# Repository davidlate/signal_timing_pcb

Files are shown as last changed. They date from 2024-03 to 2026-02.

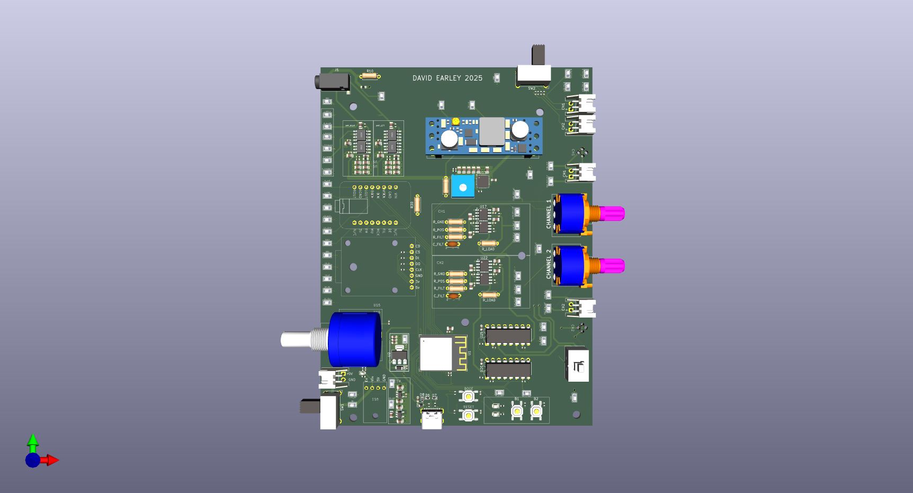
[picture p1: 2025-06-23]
20250622_SignalTimingProject_3DModelView_Rev5.png

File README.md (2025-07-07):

# Signal Timing PCB
This is a project to produce repeated audio pulses which are precisely timed with the outputs of two
current regulated, square wave AC outputs

This repo is divided into header files and functions for the various parts of the project to allow for testing each component individually

-sdcard operations
-I2S op
-DAC ops
-RMT ops
-GPTimer ops

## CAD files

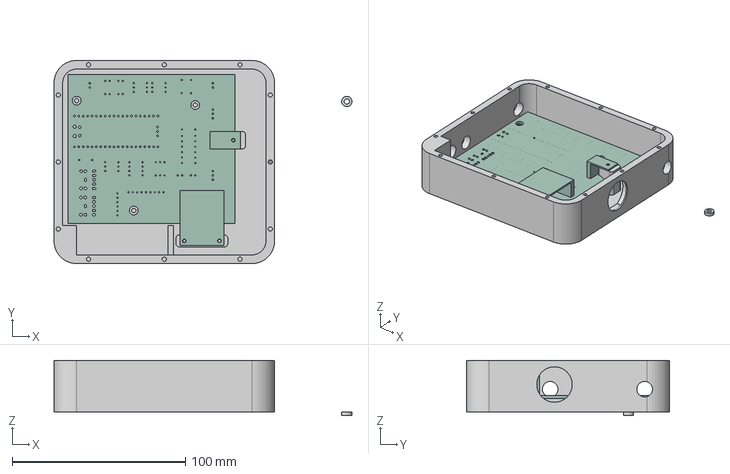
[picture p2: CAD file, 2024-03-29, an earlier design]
app/Archive/rev_1/fixture/bimodal_device_fixture v12.step
172.2 x 117.4 x 32.0 mm

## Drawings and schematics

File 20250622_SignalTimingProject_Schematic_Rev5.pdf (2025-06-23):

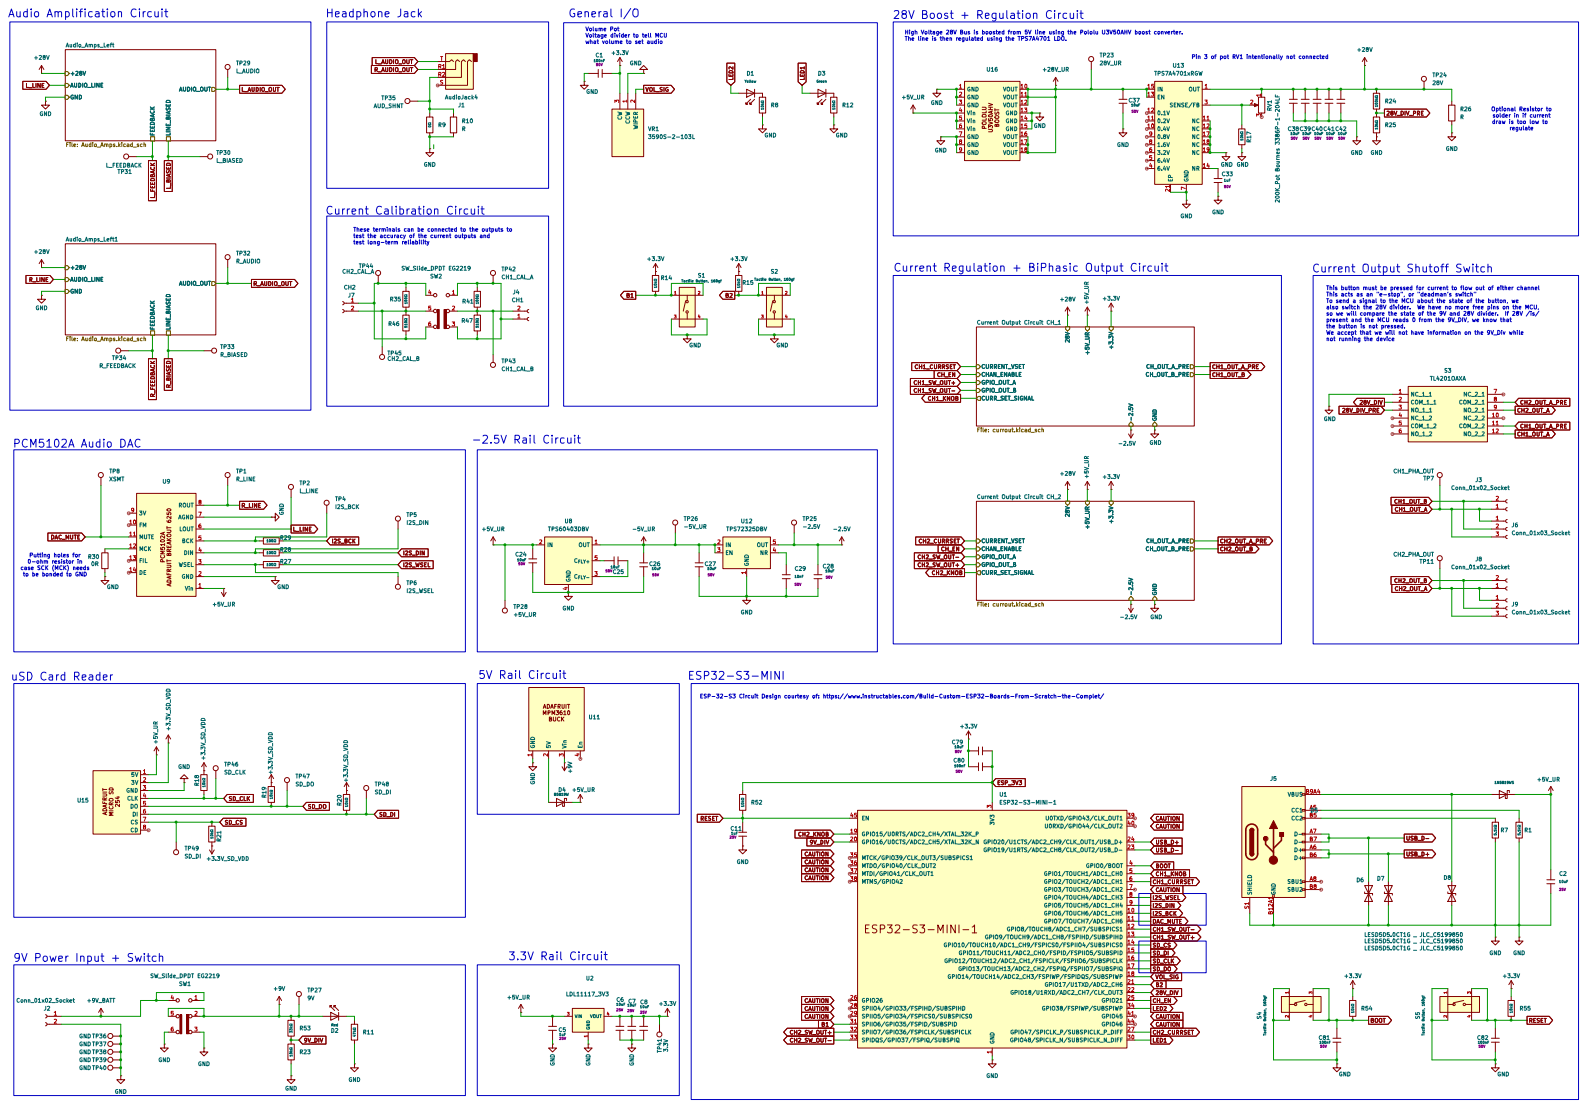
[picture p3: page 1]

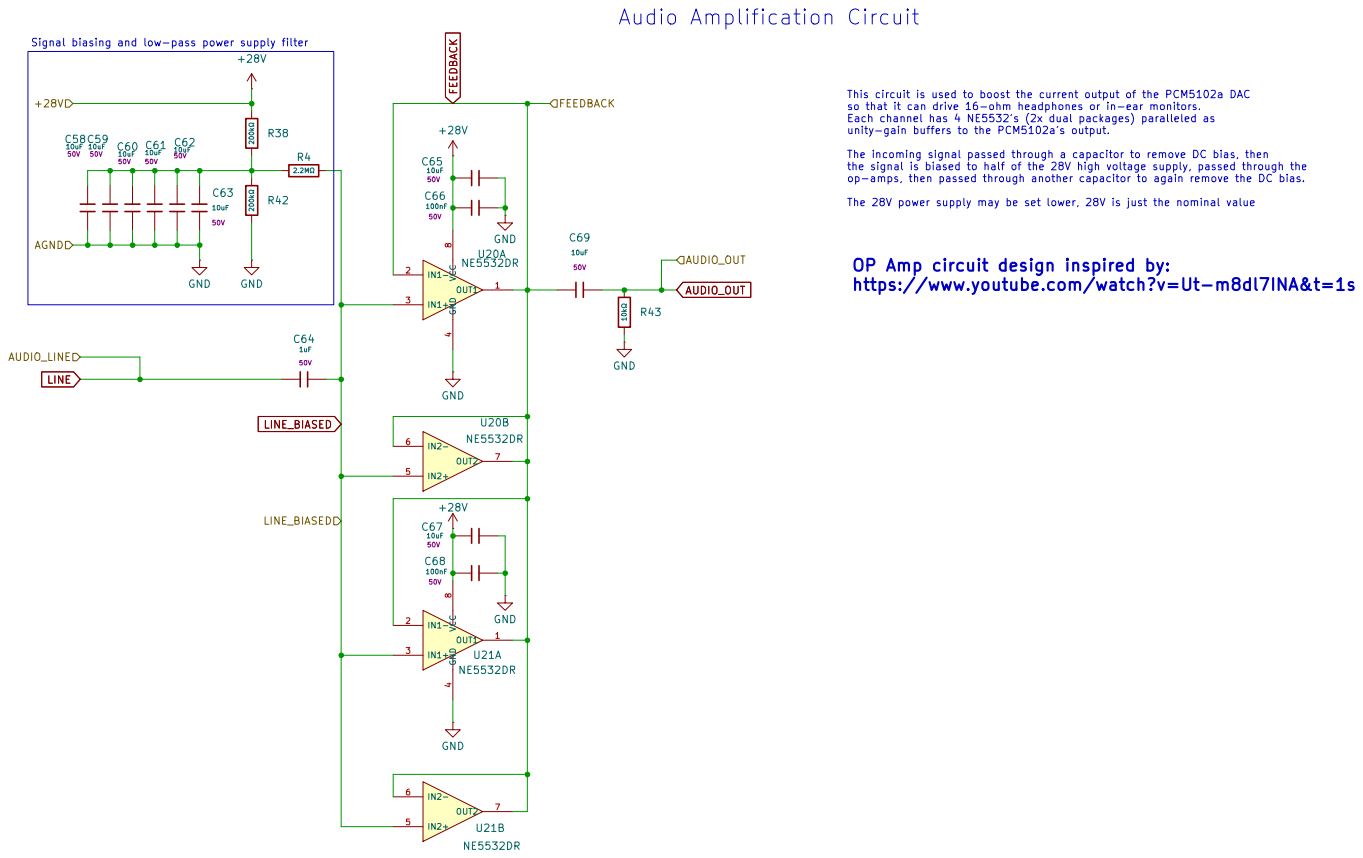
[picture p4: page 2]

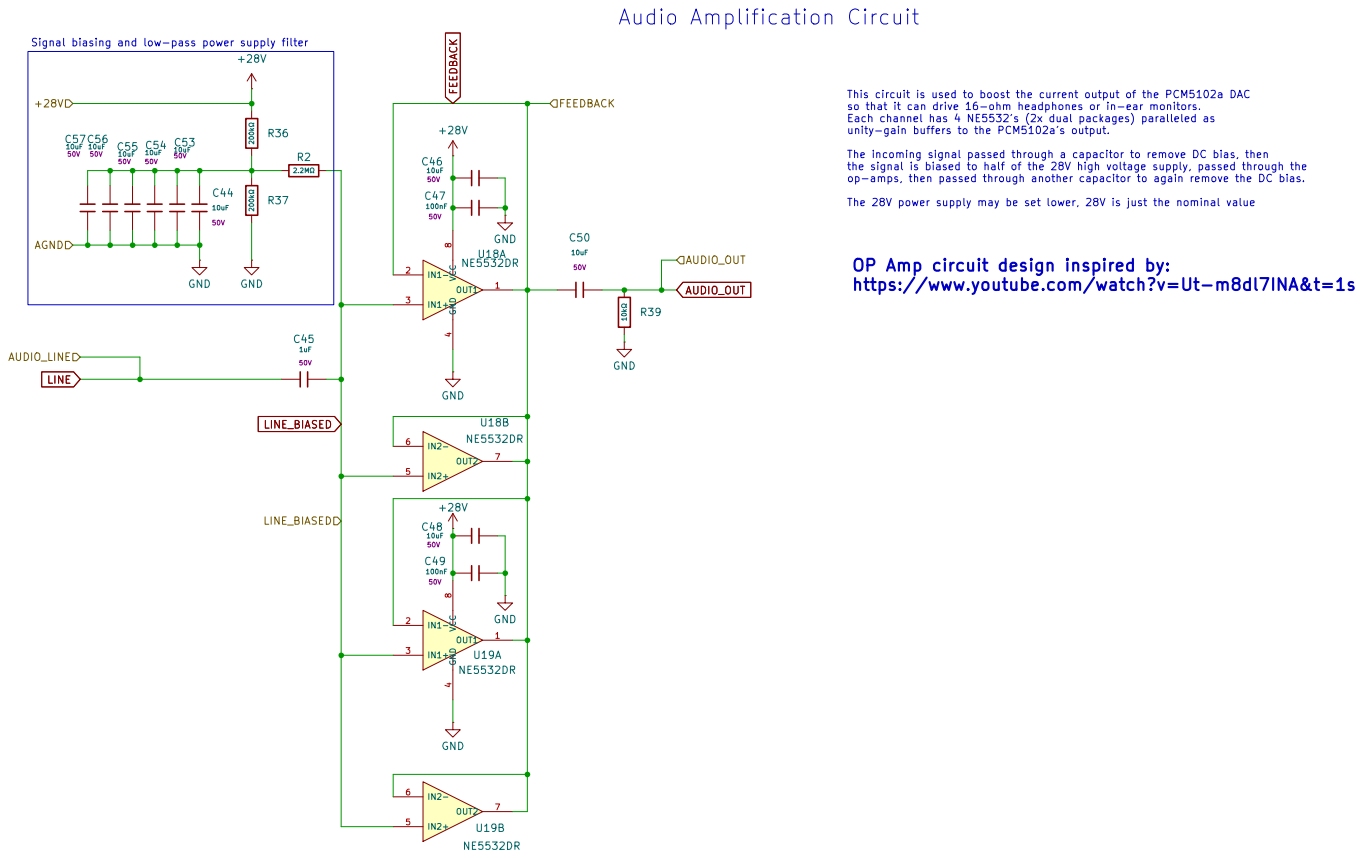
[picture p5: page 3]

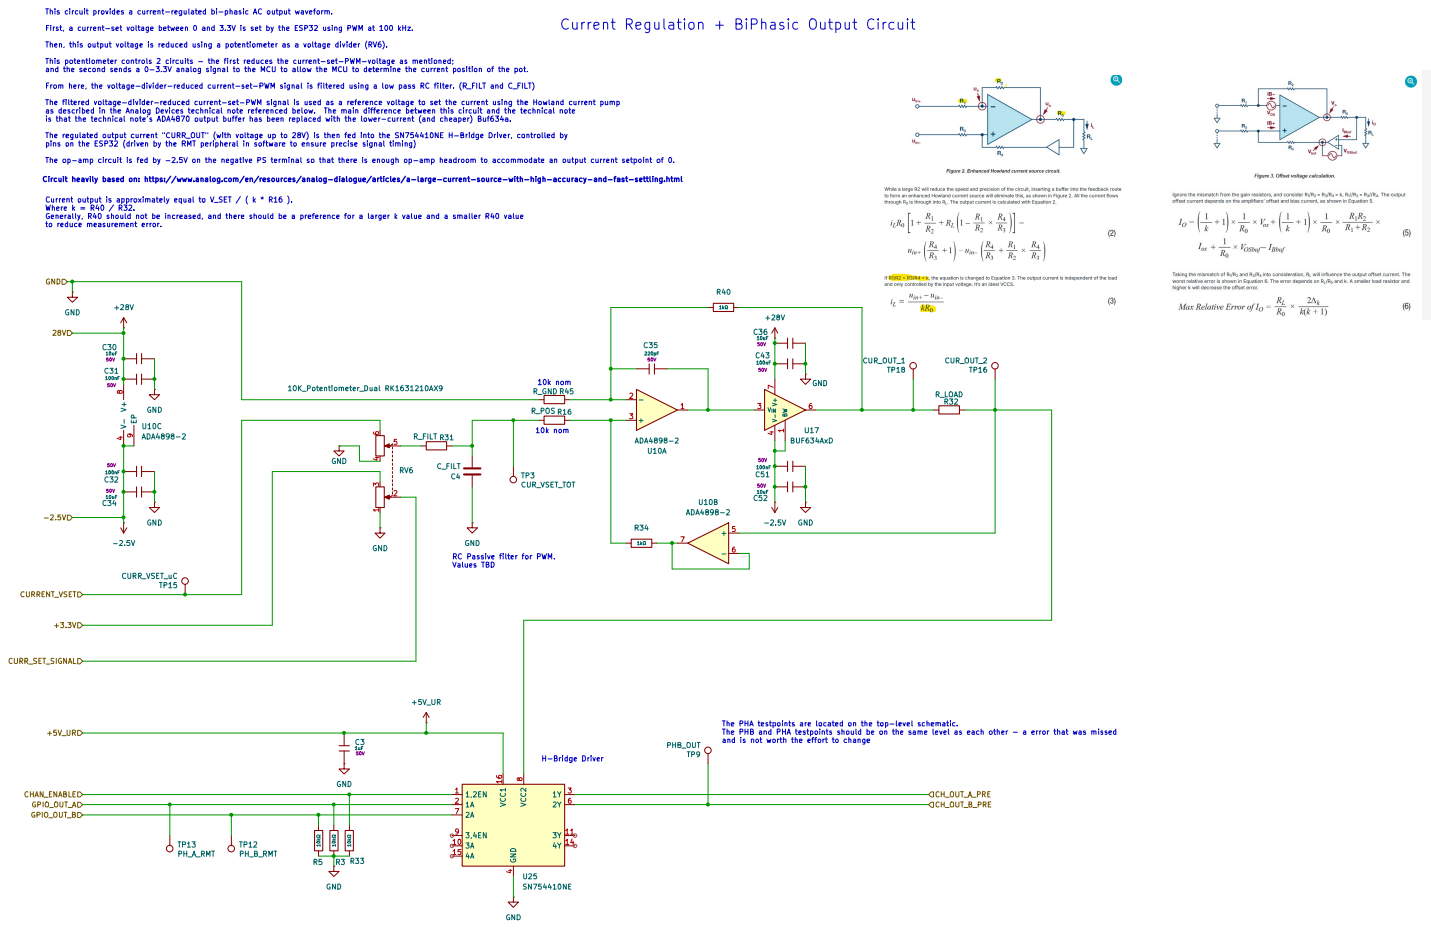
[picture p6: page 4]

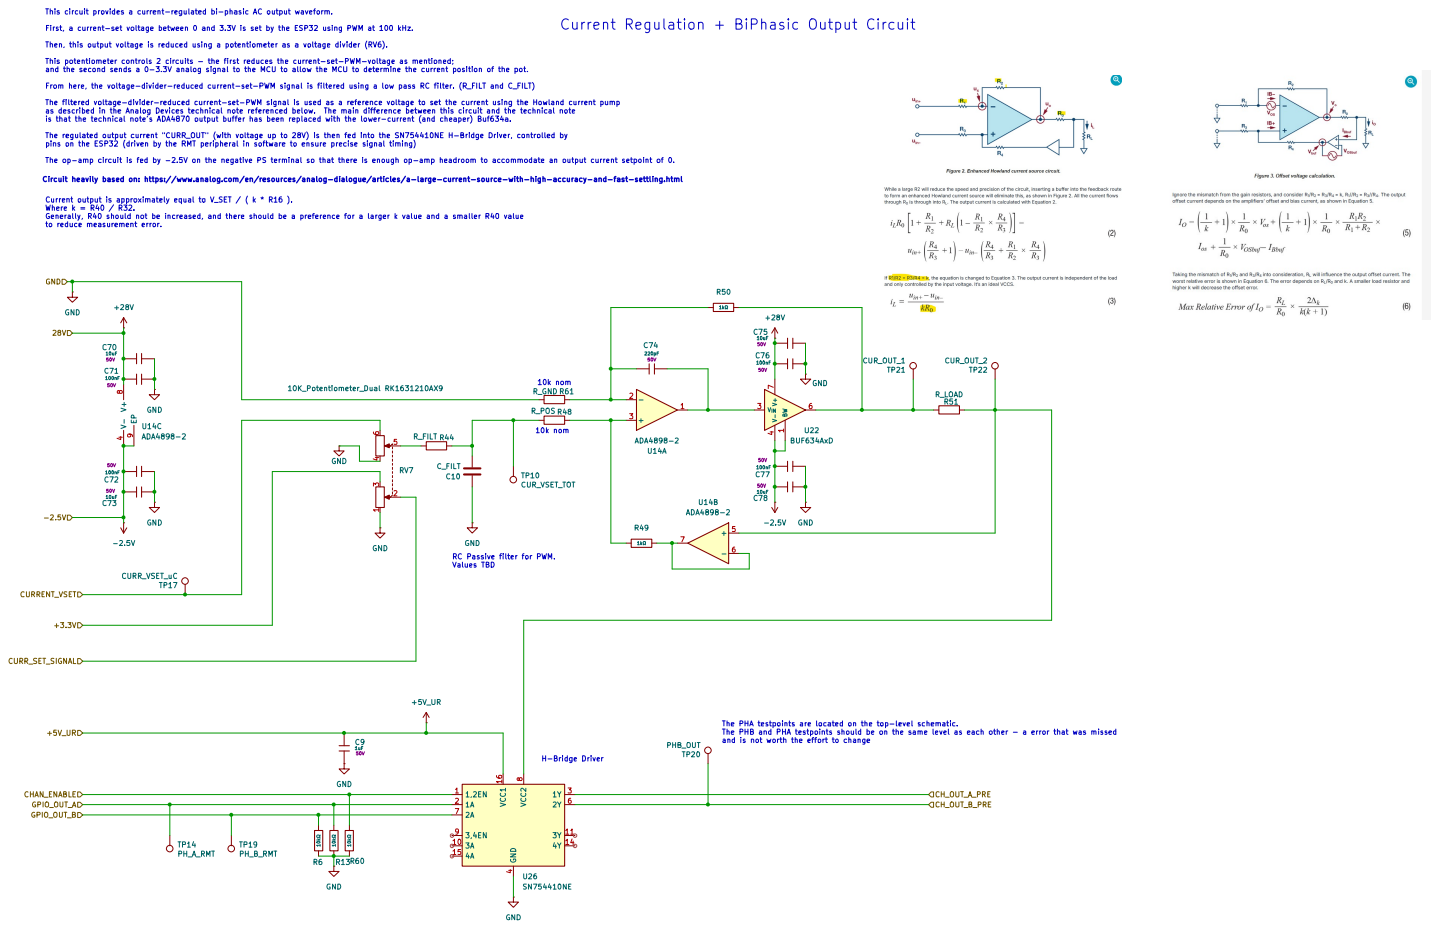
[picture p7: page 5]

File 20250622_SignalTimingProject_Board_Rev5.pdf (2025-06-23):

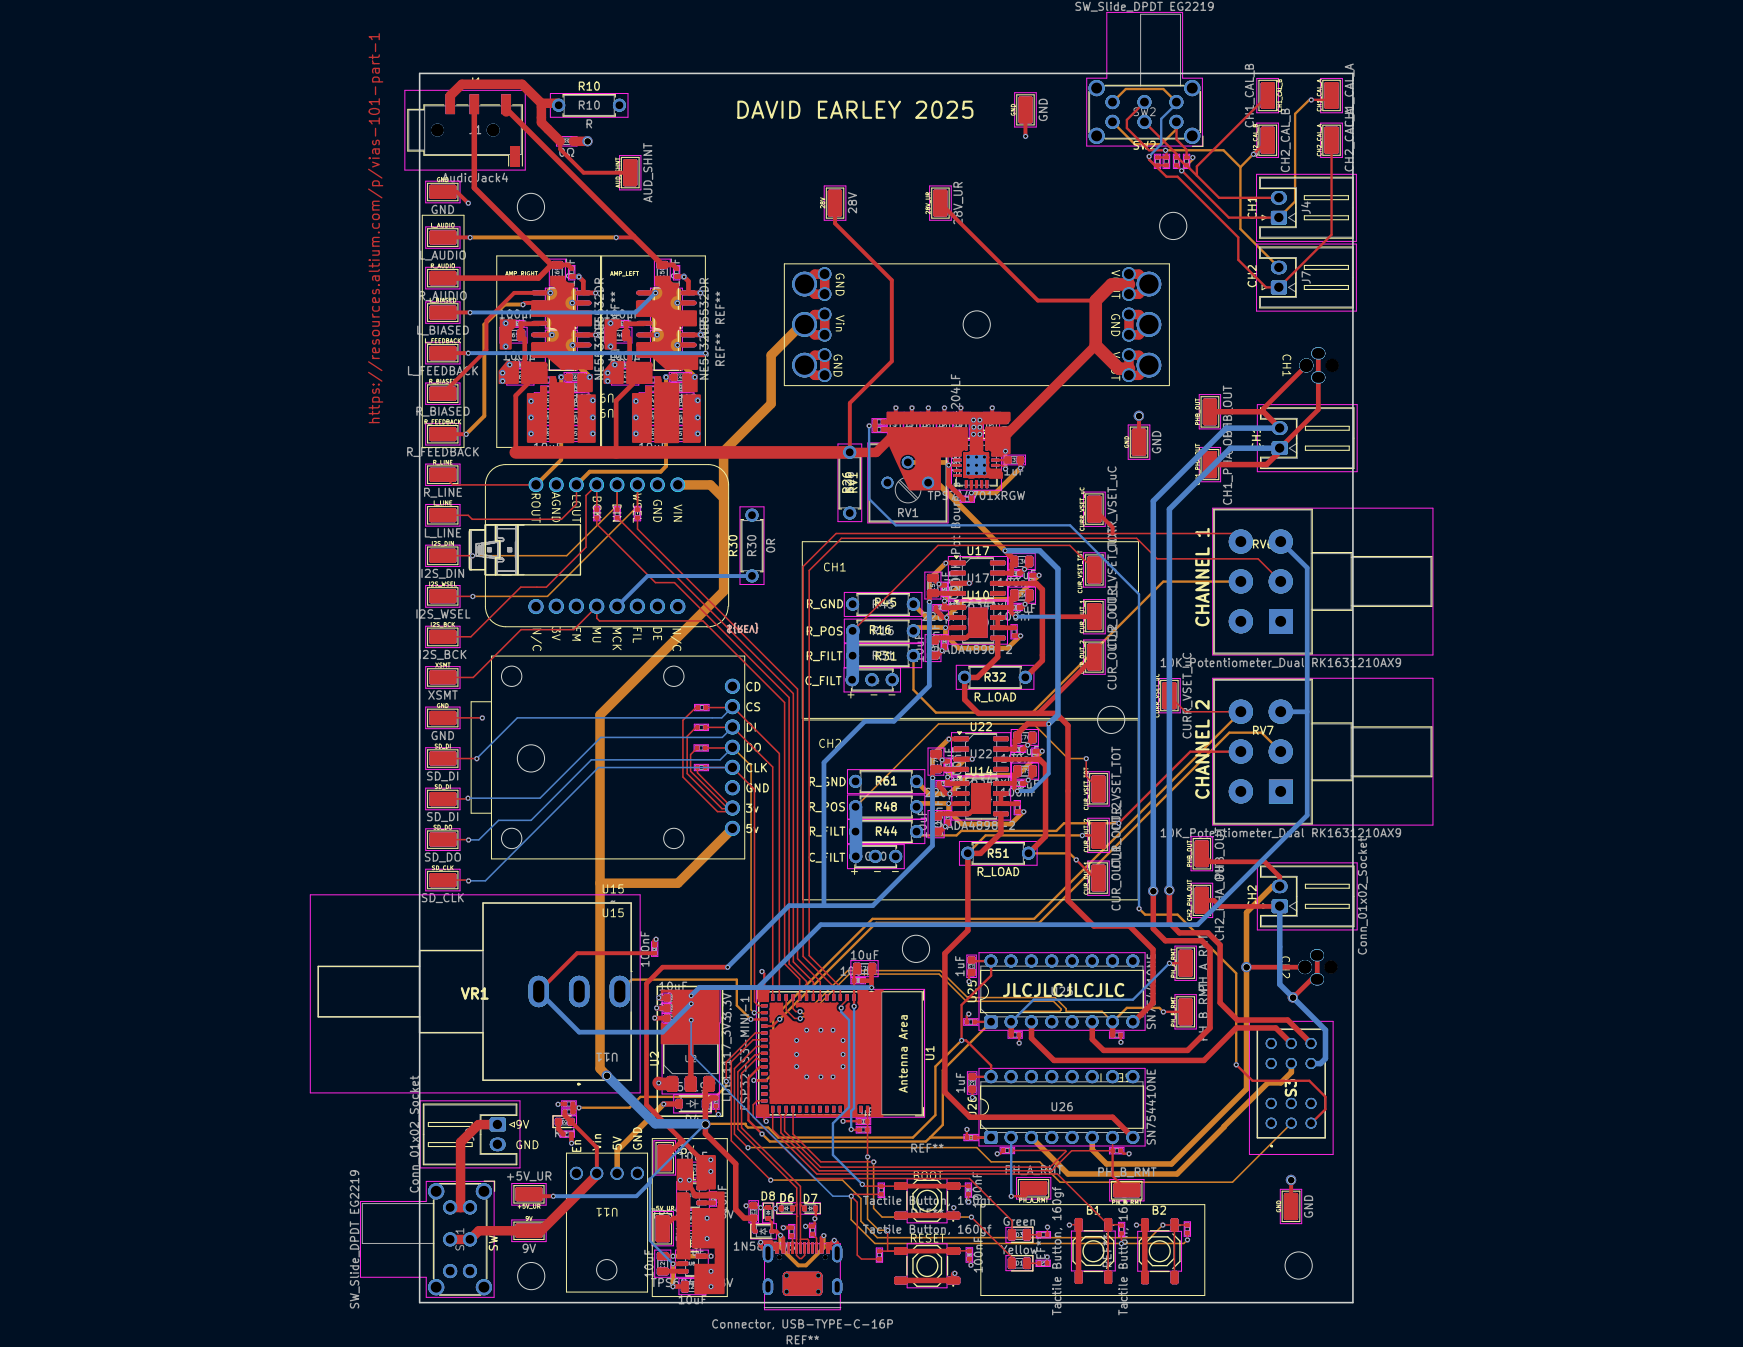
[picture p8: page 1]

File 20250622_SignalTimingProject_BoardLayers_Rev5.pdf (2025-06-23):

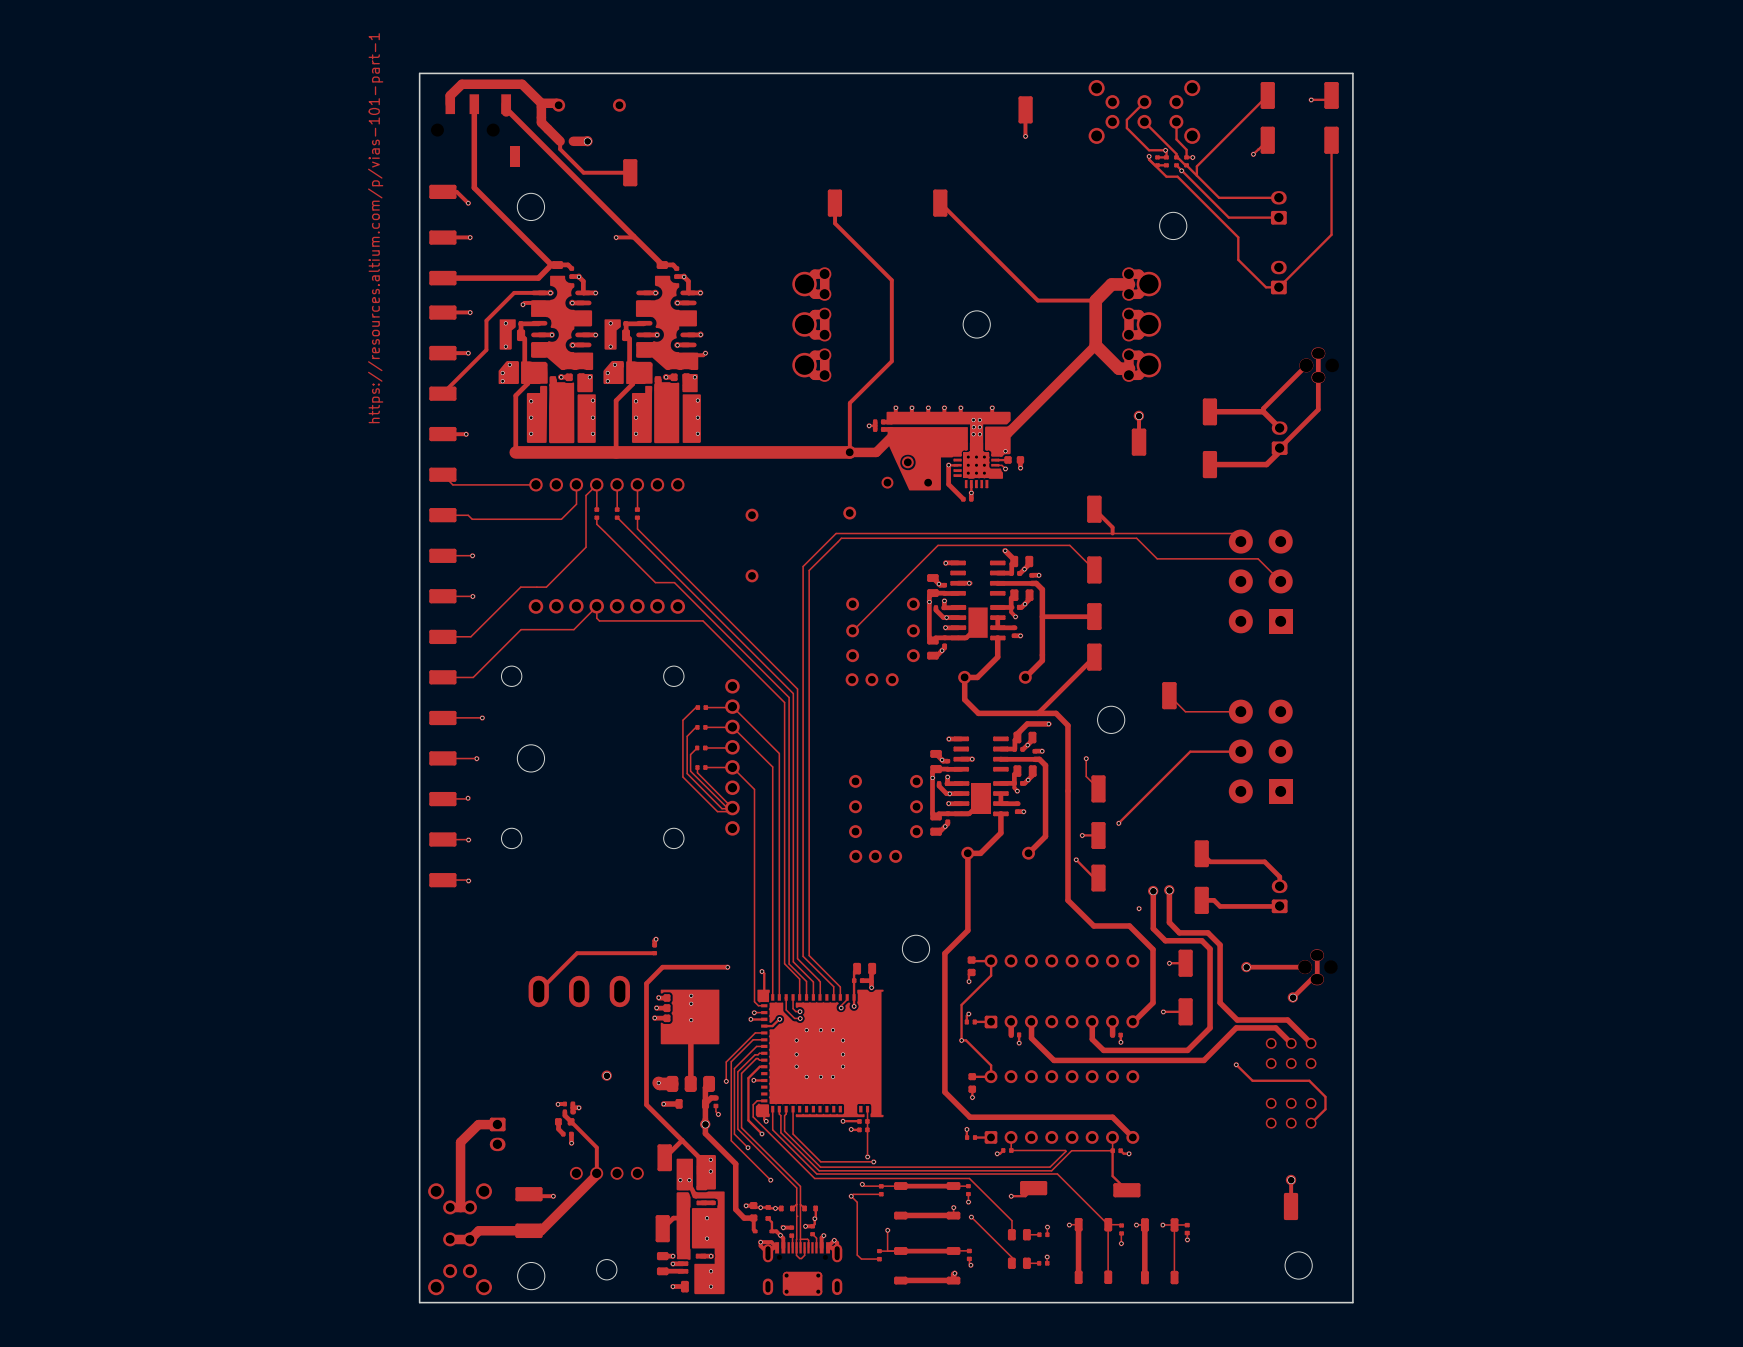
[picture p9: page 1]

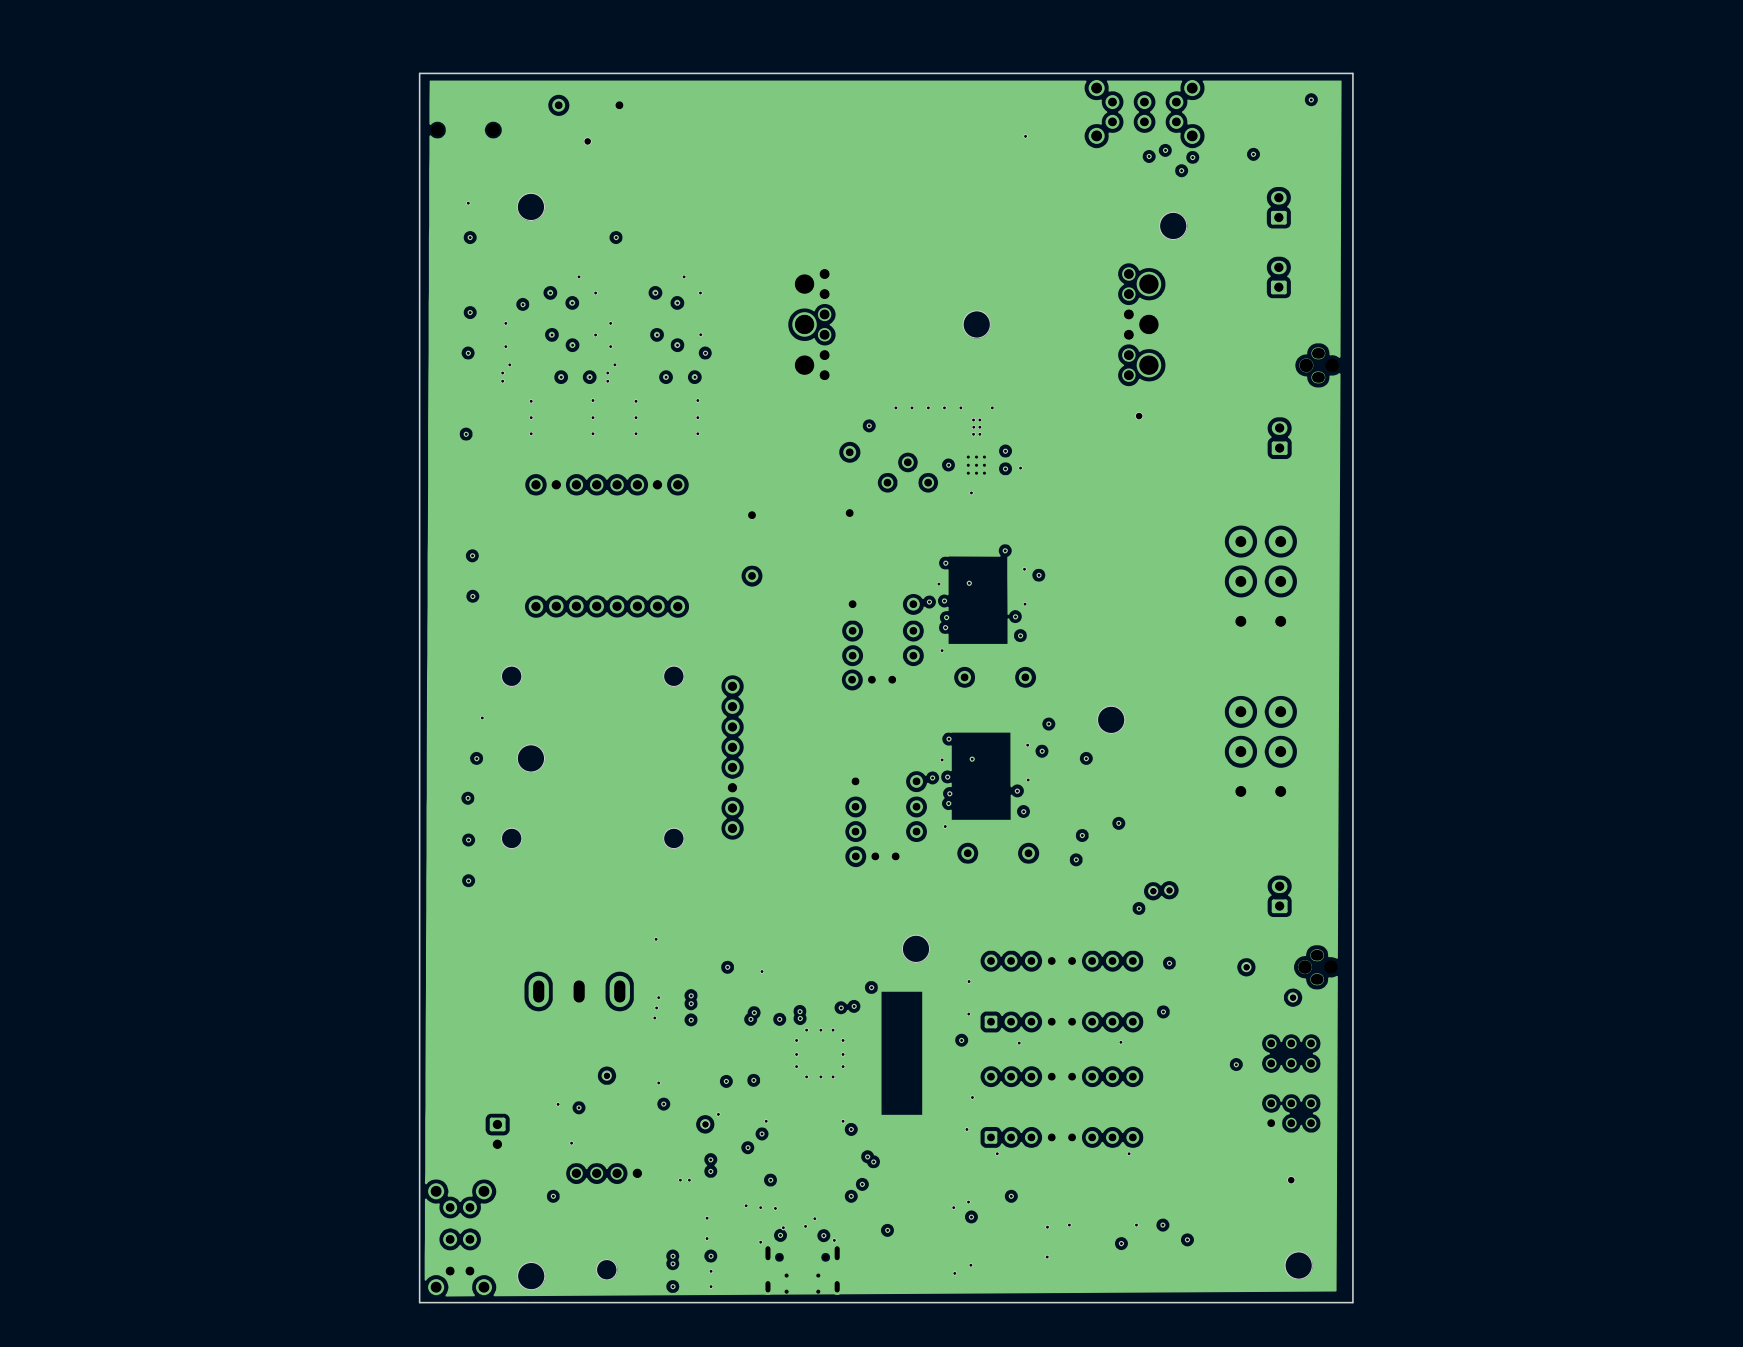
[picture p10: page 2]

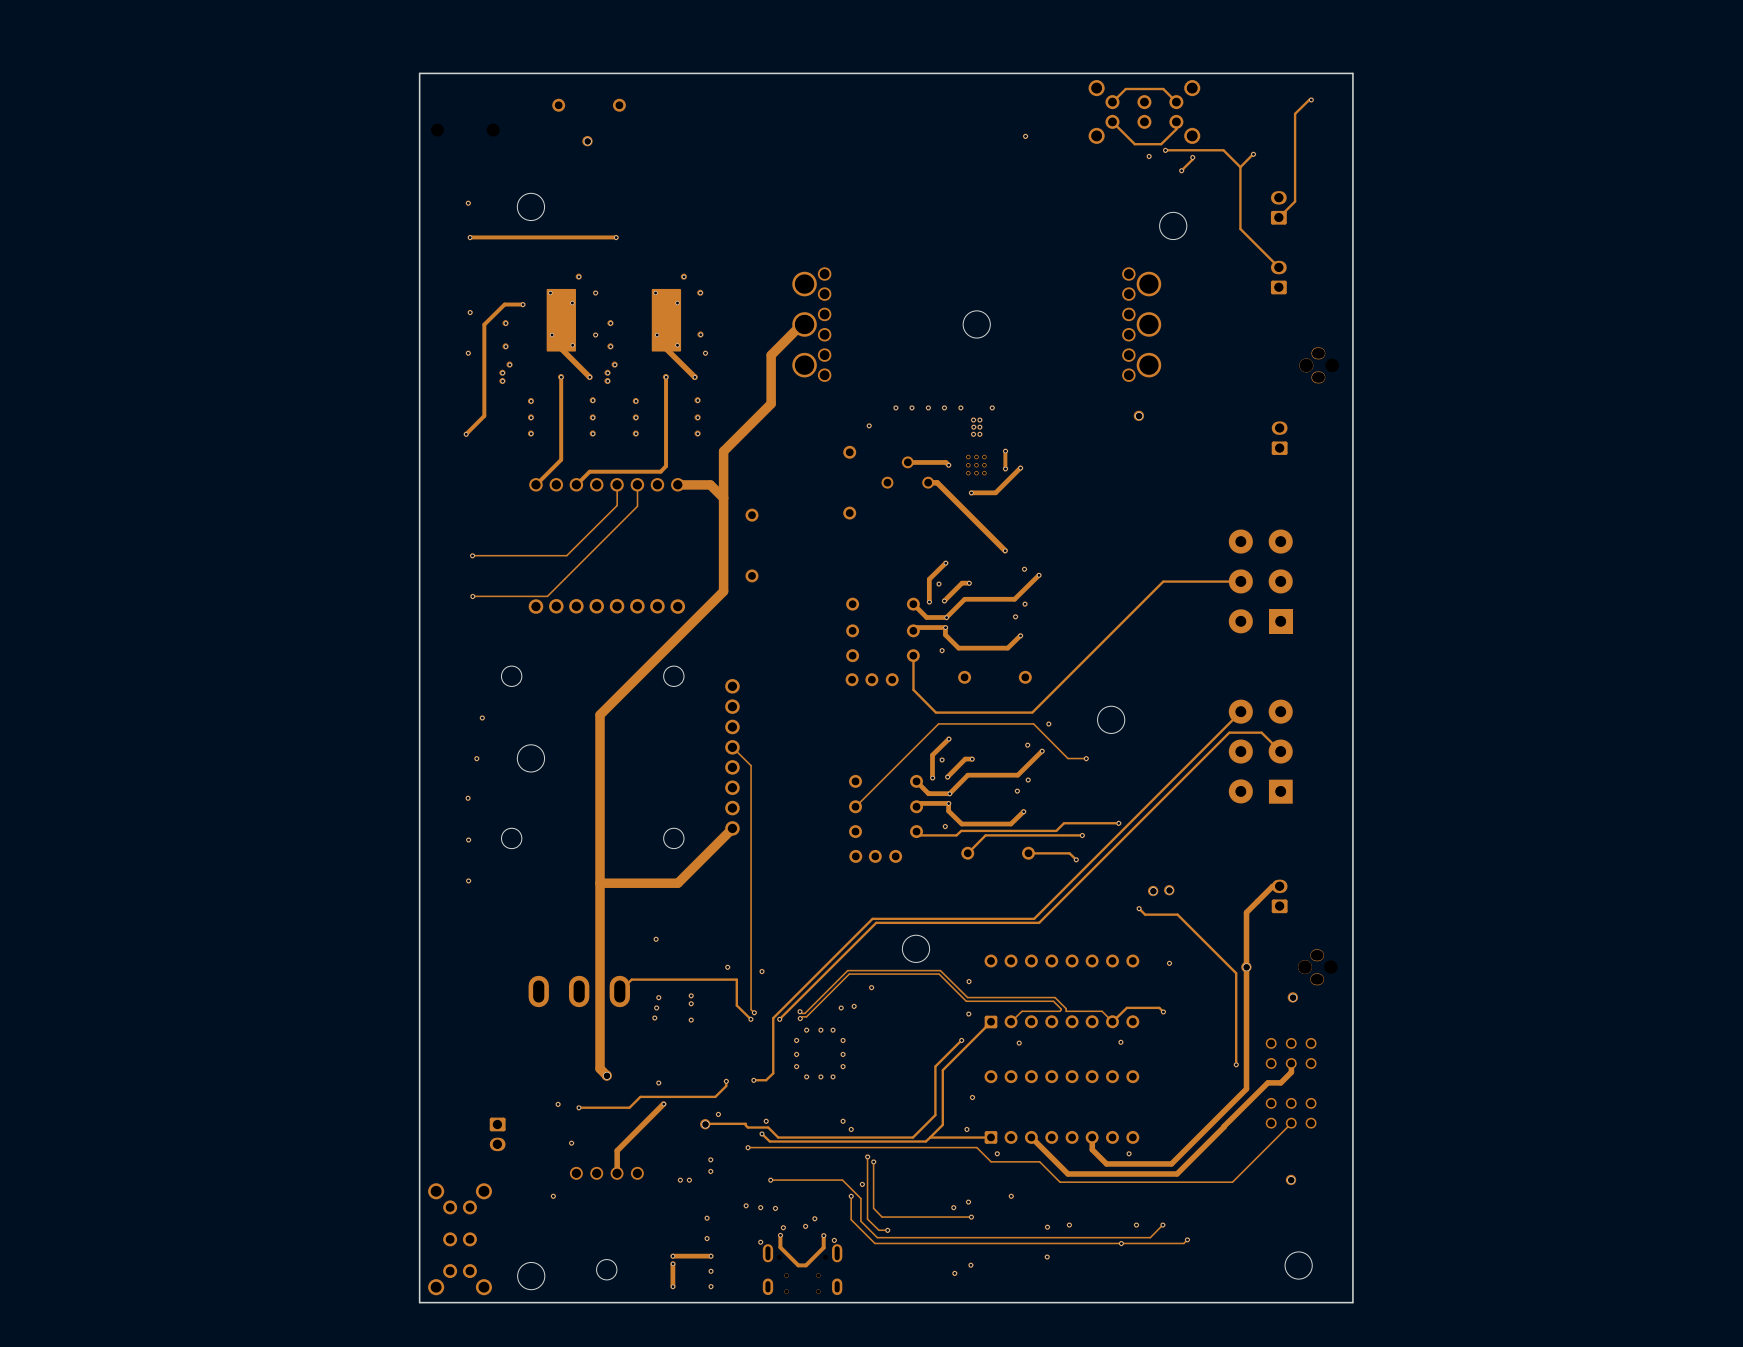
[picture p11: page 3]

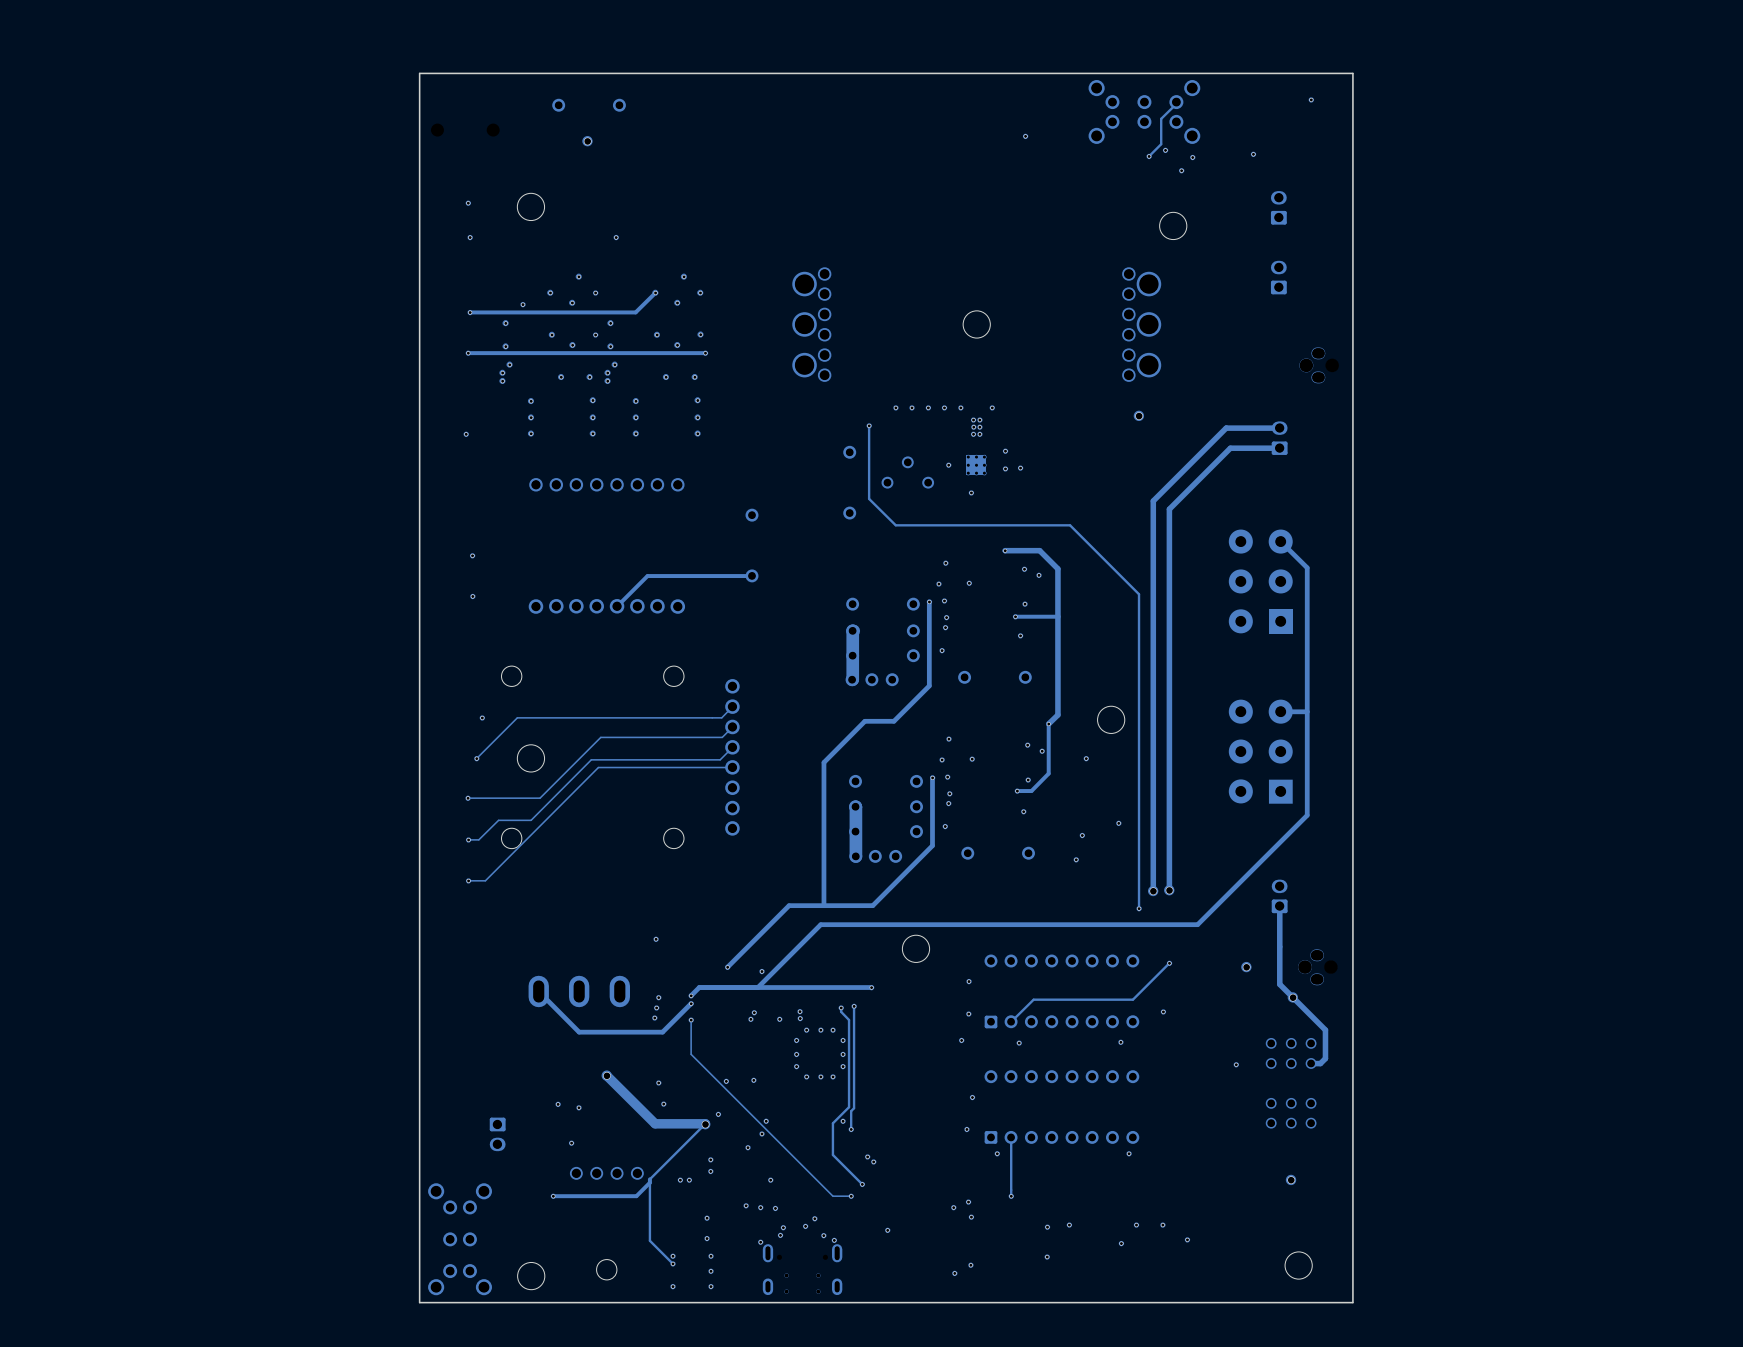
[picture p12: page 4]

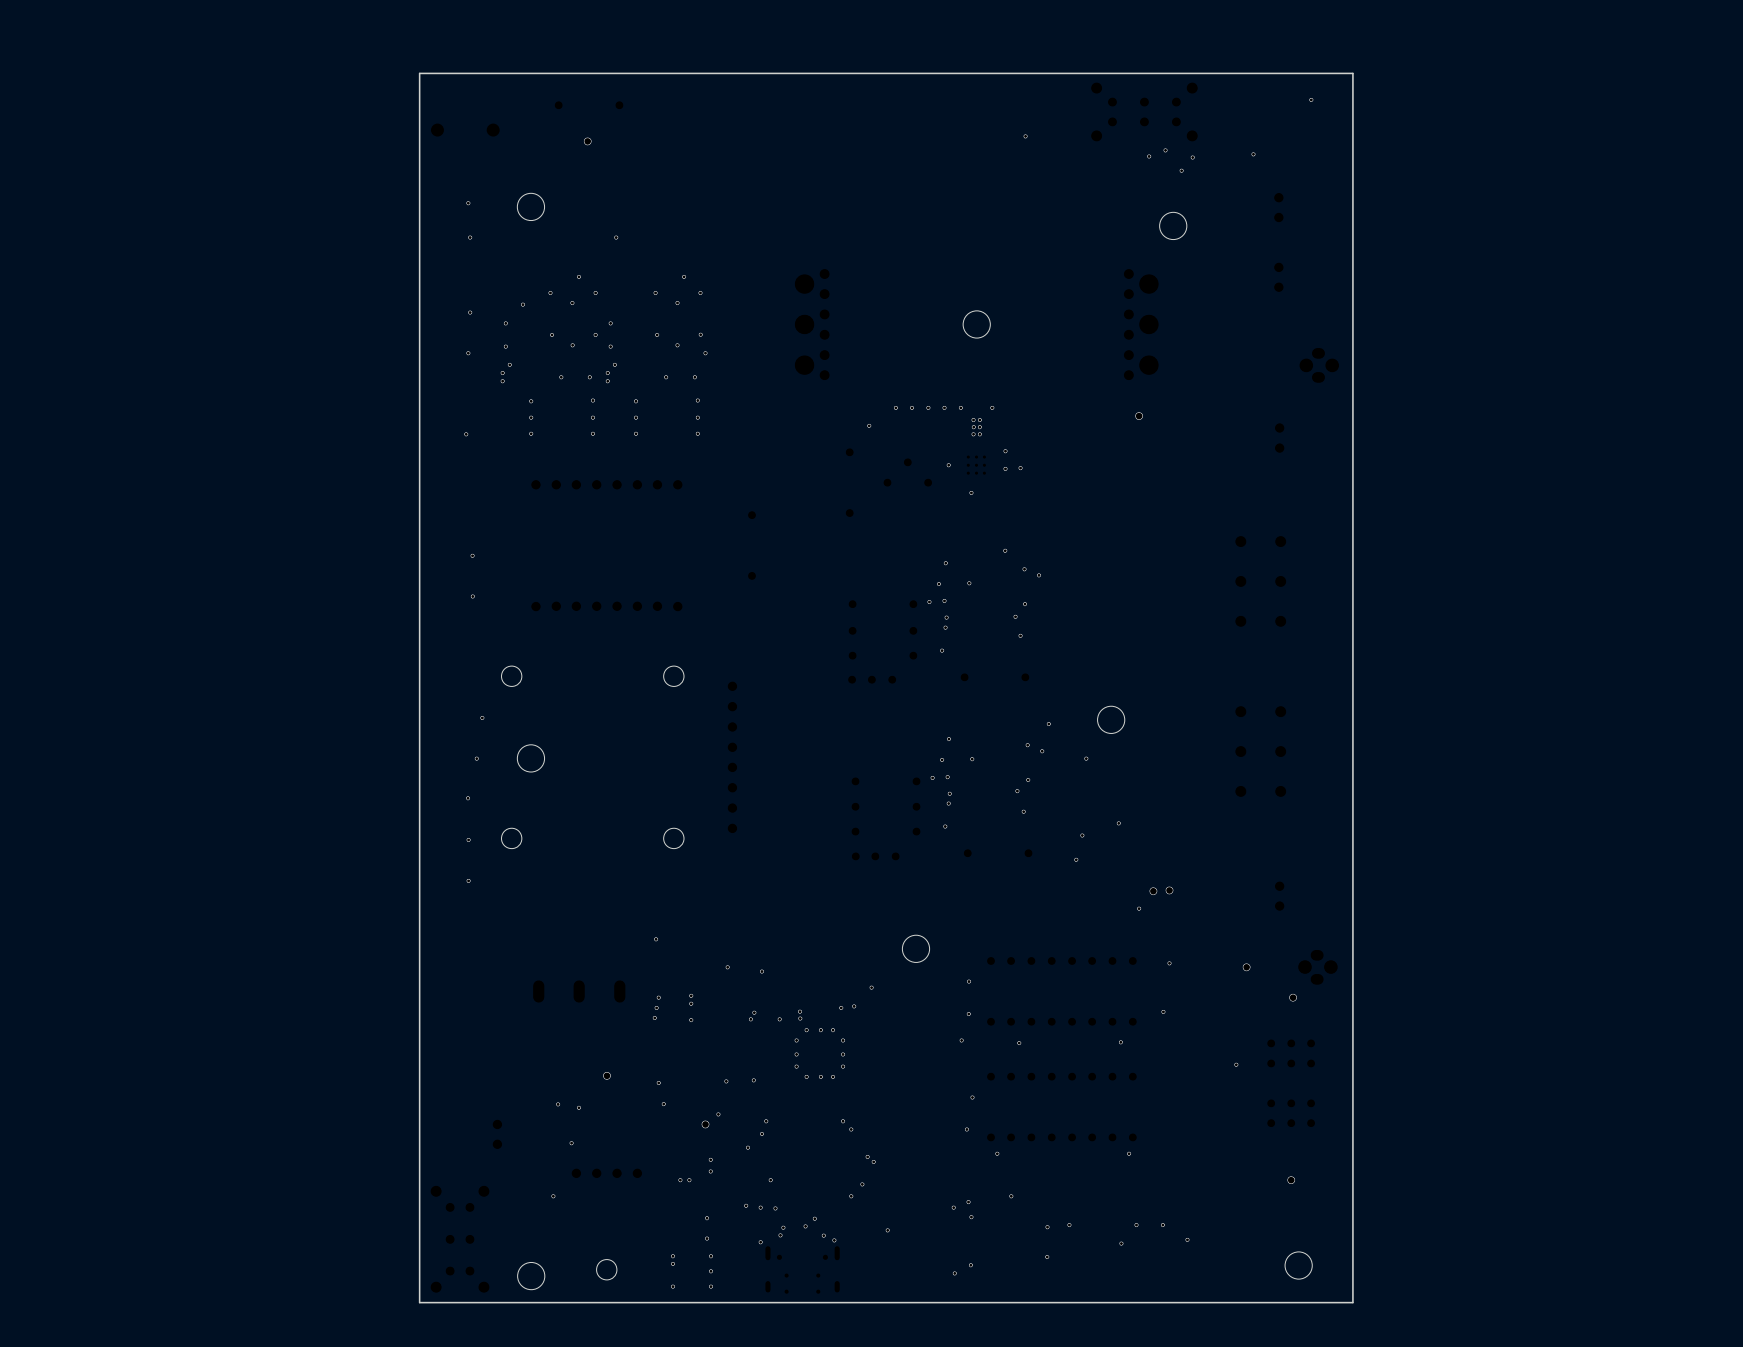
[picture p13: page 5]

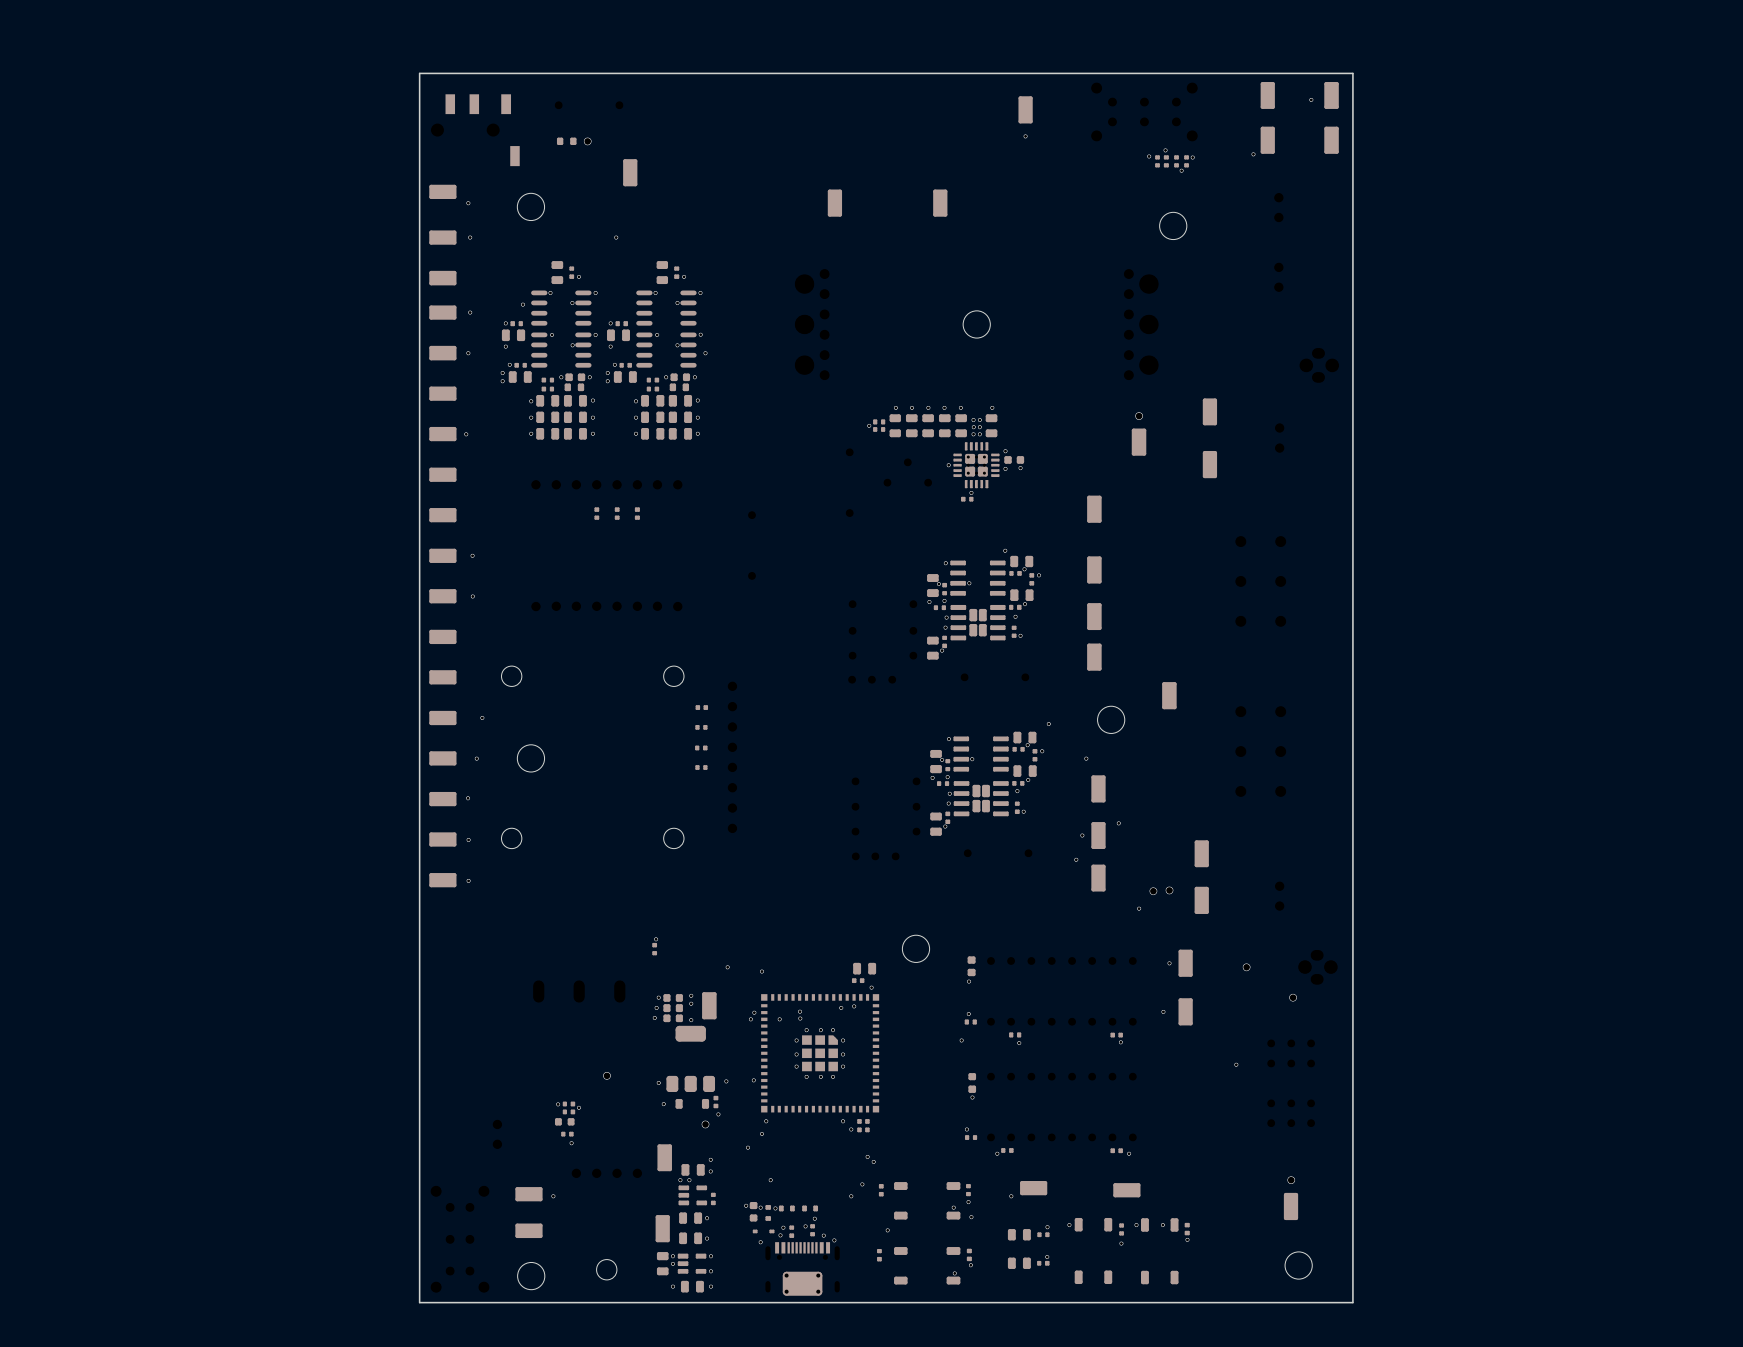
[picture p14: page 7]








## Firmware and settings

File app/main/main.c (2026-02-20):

/* SD card_ptr and FAT filesystem example.
   This example uses SPI peripheral to communicate with SD card_ptr.
*/

//This program is written by David Earley (2025) 
//This program borrows heavily from this article and the Espressif examples throughout:
//https://truelogic.org/wordpress/2015/09/04/parsing-a-wav-file-in-c/

#include <string.h>
#include <sys/unistd.h>
#include <sys/stat.h>
#include "esp_vfs_fat.h"
#include "sdmmc_cmd.h"
#include "sd_test_io.h"
#include <stdio.h>
#include <stdlib.h>
#include <dirent.h> 
#include <inttypes.h>
#include "esp_random.h"
#include "math.h"
#include "esp_timer.h"
#include "driver/gpio.h"
#include "hal/adc_types.h"
#include "esp_adc/adc_oneshot.h"
#include "freertos/queue.h"

#include "driver/ledc.h"
#include "driver/rmt_tx.h"
#include "driver/gptimer.h"
#include <driver/ledc.h>

#include "stp_sd_sdcardops.h"
#include "stp_audio__audio_ops.h"
#include "stp_adc.h"


//SD Card operation defines
#define AUDIO_FILENAME "/SINEA.wav"
// #define AUDIO_FILENAME "/WHITE.wav"

#define PIN_NUM_MISO  GPIO_NUM_13   //DO
#define PIN_NUM_MOSI  GPIO_NUM_11   //DI
#define PIN_NUM_CLK   GPIO_NUM_12   //CLK
#define PIN_NUM_CS    GPIO_NUM_10   //CS

//General IO defines
#define LED1_PIN    48          //GPIO enums only go up to 38
#define LED2_PIN    GPIO_NUM_38
#define XSMT_PIN    GPIO_NUM_7
#define B1_PIN      GPIO_NUM_35
#define B2_PIN      GPIO_NUM_17
//#define CH_EN_PIN   GPIO_NUM_21     //H-bridge enable pin

//ADC Pin and channel defines from schematic and https://www.luisllamas.es/en/esp32-s3-hardware-details-pinout/
//See example https://github.com/espressif/esp-idf/blob/v4.4/examples/peripherals/adc/single_read/single_read/main/single_read.c
#define VOL_PIN         GPIO_NUM_14     //Volume sample DAC pin
#define VOL_ADC_UNIT    ADC_UNIT_2
#define VOL_ADC_CHAN    ADC_CHANNEL_3
#define CH1_KNOB_PIN    GPIO_NUM_1      //Status of ch1 knob DAC pin
#define CH1_ADC_UNIT    ADC_UNIT_1
#define CH1_ADC_CHAN    ADC_CHANNEL_0
#define CH2_KNOB_PIN    GPIO_NUM_15     //Status of ch2 knob DAC pin
#define CH2_ADC_UNIT    ADC_UNIT_2
#define CH2_ADC_CHAN    ADC_CHANNEL_4
#define BATT_PIN        GPIO_NUM_16     //9VDIV battery sample DAC pin
#define BATT_ADC_UNIT   ADC_UNIT_2
#define BATT_ADC_CHAN   ADC_CHANNEL_5
#define HVDIV_PIN       GPIO_NUM_18     //28VDIV pin
#define HVDIV_ADC_UNIT  ADC_UNIT_2
#define HVDIV_ADC_CHAN  ADC_CHANNEL_7

//PWM Pin defines QUOTE: https://randomnerdtutorials.com/esp-idf-esp32-gpio-pwm-ledc/
#define CH1_CURSET_PIN  GPIO_NUM_2
#define CH1_CURSET_CHANNEL LEDC_CHANNEL_0
#define CH1_CURSET_TIMER LEDC_TIMER_0
#define CH1_CURSET_MODE LEDC_LOW_SPEED_MODE
#define CH1_CURSET_DUTY_RES LEDC_TIMER_8_BIT 
#define CH1_CURSET_FREQUENCY 200000             // 1 kHz PWM frequency

#define CH2_CURSET_PIN  GPIO_NUM_47

//ENDQUOTE

//RMT Pin defines
#define CH1_SW_OUTA_PIN     GPIO_NUM_8  //CH1_SW_OUT+   //TODO: This should be pin 9
#define CH1_SW_OUTB_PIN     GPIO_NUM_21  //CH1_SW_OUT-   //   Using the ch_en pin of GPIO21, GPIO9 is burnt out
#define CH2_SW_OUTA_PIN     GPIO_NUM_36 //CH2_SW_OUT+
#define CH2_SW_OUTB_PIN     GPIO_NUM_37 //CH2_SW_OUT-

//I2S defines
#define I2S_WS_PIN   GPIO_NUM_4      //LCK, LRC, 13 I2S word select io number
#define I2S_DOUT_PIN GPIO_NUM_5      //DIN, 12 I2S data out io number
#define I2S_BCK_PIN  GPIO_NUM_6      //BCK 11  I2S bit clock io number

#define SAMPLE_RATE    96000
#define NUM_DMA_BUFF   8
#define SIZE_DMA_BUFF  500         //can go up to 500

#define MAX_VOL_DBFS            -20
#define MIN_VOL_DBFS            -60

#define AUDIO_PLAY_INTERVAL_MS              1000
#define PCM5102A_LATENCY_COMPENSATION_US    4975                    
#define PRE_DITHER_MS                       0

#define RMT_PLAY_DELAY_MS                       10+PCM5102A_LATENCY_COMPENSATION_US/1000

#define ADC_UPDATE_PERIOD_MS    100
#define PRINT_UPDATE_PERIOD_MS  100
#define BACKGROUND_TASK_PRIORTIY 1
#define AUDIO_TASK_PRIORITY      5
#define RMT_TASK_PRIORITY        7

#define RMT_TASK_CORE            1
#define AUDIO_TASK_CORE          0

typedef struct {
    SemaphoreHandle_t         adc_mutex;
    stp_adc__adc_chan_results adc_results;
} Adc_Update_Struct;

typedef struct {
    stp_audio__i2s_config* i2s_config_ptr;
    stp_sd__audio_chunk* audio_chunk_ptr;
    stp_sd__wavFile* wave_file_ptr;
    Adc_Update_Struct* adc_update_struct_ptr;
    TaskHandle_t rmt_task_to_notify;
    QueueHandle_t rmt_start_queue;
    bool (*rmt_callback_func_ptr)(struct gptimer_t *, const gptimer_alarm_event_data_t *, void *);
} Audio_Task_Setup_Struct;

void flash_lights(void * pvParameters){

    gpio_set_direction(XSMT_PIN, GPIO_MODE_OUTPUT);
    gpio_set_direction(LED1_PIN, GPIO_MODE_OUTPUT);
    gpio_set_direction(LED2_PIN, GPIO_MODE_OUTPUT);

    gpio_set_level(LED1_PIN, 0);
    gpio_set_level(LED2_PIN, 0);
    gpio_set_level(XSMT_PIN, 0);

    gpio_set_direction(LED2_PIN, GPIO_MODE_OUTPUT);
    gpio_set_level(LED1_PIN, 0);


    while(true){
        gpio_set_level(LED1_PIN, 1);
        gpio_set_level(LED2_PIN, 0);
        vTaskDelay(pdMS_TO_TICKS(500));
        gpio_set_level(LED1_PIN, 0);
        gpio_set_level(LED2_PIN, 1);
        vTaskDelay(pdMS_TO_TICKS(500));
    }
}

void update_adc(void* pvParameters){

    Adc_Update_Struct* adc_update_struct = (Adc_Update_Struct*)pvParameters;
    
    stp_adc__adc_setup_struct adc_chan_setup = {
        .vol_adc_unit  = VOL_ADC_UNIT,
        .vol_adc_chan  = VOL_ADC_CHAN,
        .ch1_adc_unit  = CH2_ADC_UNIT,  //TODO fix
        .ch1_adc_chan  = CH2_ADC_CHAN,  //TODO fix
        .ch2_adc_unit  = CH2_ADC_UNIT,
        .ch2_adc_chan  = CH2_ADC_CHAN,
        .batt_adc_unit = BATT_ADC_UNIT,
        .batt_adc_chan = BATT_ADC_CHAN,
        .hv_adc_unit   = HVDIV_ADC_UNIT,
        .hv_adc_chan   = HVDIV_ADC_CHAN,
    };

    stp_adc__adc_chan_struct adc_chan_struct;
    stp_adc__setup_adc_chans(adc_chan_setup, &adc_chan_struct);

    //QUOTE: https://randomnerdtutorials.com/esp-idf-esp32-gpio-pwm-ledc/
    ledc_timer_config_t ledc_timer = {
        .speed_mode = CH1_CURSET_MODE,
        .duty_resolution = CH1_CURSET_DUTY_RES,
        .timer_num = CH1_CURSET_TIMER,
        .freq_hz = CH1_CURSET_FREQUENCY
    };
    ledc_timer_config(&ledc_timer);

    // Configure LEDC channel
    ledc_channel_config_t ledc_channel = {
        .gpio_num = CH1_CURSET_PIN,
        .speed_mode = CH1_CURSET_MODE,
        .channel = CH1_CURSET_CHANNEL,
        .timer_sel = CH1_CURSET_TIMER,
        .duty = 0
    };
    ledc_channel_config(&ledc_channel);
    //ENDQUOTE
    int ch1_duty = 0;
    int ch1_duty_bits = pow(2, CH1_CURSET_DUTY_RES)-1;
    double ch1_percent = 0;
    while (true)
    {
        if(xSemaphoreTake(adc_update_struct->adc_mutex, portMAX_DELAY)==pdTRUE)
        {
            stp_adc__read_all_adc_chans(&adc_chan_struct, &(adc_update_struct->adc_results));
            ch1_percent = adc_update_struct->adc_results.ch1_percent;
            xSemaphoreGive(adc_update_struct->adc_mutex);
            // if(ch1_percent < 40) ch1_percent = 40;
            ch1_duty = ch1_percent/100*(ch1_duty_bits);
            ledc_set_duty(CH1_CURSET_MODE, CH1_CURSET_CHANNEL, ch1_duty);
            ledc_update_duty(CH1_CURSET_MODE, CH1_CURSET_CHANNEL);
            vTaskDelay(pdMS_TO_TICKS(ADC_UPDATE_PERIOD_MS));
        }
    }
}

void print_to_terminal(void* pvParameters){
    vTaskDelay(pdMS_TO_TICKS(100));
    Adc_Update_Struct* adc_update_struct = (Adc_Update_Struct*)pvParameters;

    while (true)
    {
        if (xSemaphoreTake(adc_update_struct->adc_mutex, portMAX_DELAY) == pdTRUE)
        {
            stp_adc__adc_chan_results adc_results = adc_update_struct->adc_results;
            xSemaphoreGive(adc_update_struct->adc_mutex);

            printf("\rVol: %.0f%% | Ch2: %0.0f%% | Ch1: %0.0f%% |Batt: %.1fV | HV: %.1fV  ",
                adc_results.vol_percent,
                adc_results.ch2_percent,
                adc_results.ch1_percent,
                adc_results.batt_voltage,
                adc_results.hv_voltage);
        }
        vTaskDelay(pdMS_TO_TICKS(PRINT_UPDATE_PERIOD_MS));
    }
}

static bool IRAM_ATTR start_audio_GPTimer_callback(gptimer_handle_t timer, const gptimer_alarm_event_data_t *edata, void *user_ctx)
{
    Audio_GPTimer_Args_Struct* data_ptr = (Audio_GPTimer_Args_Struct*)user_ctx;
    gptimer_start(data_ptr->rmt_gptimer_hdnl); //immediately start timer to run RMT.. There seems to be an issue with recycling this timer for repeated use
    i2s_channel_enable_from_ISR(data_ptr->tx_chan);             //start audio playing
    QueueHandle_t audio_play_queue = data_ptr->audio_start_queue;
    BaseType_t xHigherPriorityTaskWoken = pdFALSE;
    int8_t item_to_queue = 0;
    xQueueSendFromISR(audio_play_queue, &item_to_queue, &xHigherPriorityTaskWoken);

    return 0;
}

void play_audio_Task(void* pvParameters)
{
    char* TAG = "play_audio_task";
    Audio_Task_Setup_Struct* task_setup_struct_ptr = (Audio_Task_Setup_Struct*)pvParameters;
    stp_audio__i2s_config* i2s_config_ptr       = task_setup_struct_ptr->i2s_config_ptr;
    stp_sd__audio_chunk* audio_chunk_ptr        = task_setup_struct_ptr->audio_chunk_ptr;
    stp_sd__wavFile* wave_file_ptr              = task_setup_struct_ptr->wave_file_ptr;
    Adc_Update_Struct* adc_update_struct_ptr    = task_setup_struct_ptr->adc_update_struct_ptr;

    gptimer_handle_t audio_gptimer_hndl = NULL;
    gptimer_config_t timer_config = {
                                    .clk_src = GPTIMER_CLK_SRC_DEFAULT,
                                    .direction = GPTIMER_COUNT_UP,
                                    .resolution_hz = 1e6, // 1MHz, 1 tick = 1us
                                };
    ESP_ERROR_CHECK(gptimer_new_timer(&timer_config, &audio_gptimer_hndl));
    gptimer_alarm_config_t alarm_config = {
                                        .reload_count = 0, // counter will reload with 0 on alarm event
                                        .alarm_count = AUDIO_PLAY_INTERVAL_MS * 1000,
                                        .flags.auto_reload_on_alarm = true, // enable auto-reload
                                    };
    ESP_ERROR_CHECK(gptimer_set_alarm_action(audio_gptimer_hndl, &alarm_config));
    gptimer_event_callbacks_t cbs = {
        .on_alarm = start_audio_GPTimer_callback, // register user callback
    };

    QueueHandle_t start_audio_play_queue;
    start_audio_play_queue = xQueueCreate(1, sizeof(int8_t));
    if(start_audio_play_queue == NULL) ESP_LOGE(TAG, "Error creating audio play queue!");

    gptimer_handle_t rmt_gptimer = NULL;
    gptimer_config_t rmt_timer_config = {
        .clk_src = GPTIMER_CLK_SRC_DEFAULT, // Select the default clock source
        .direction = GPTIMER_COUNT_UP,      // Counting direction is up
        .resolution_hz = 1e6,   // Resolution is 1 MHz, i.e., 1 tick equals 1 microsecond
    };
    // Create a timer instance
    ESP_ERROR_CHECK(gptimer_new_timer(&rmt_timer_config, &rmt_gptimer));

    gptimer_alarm_config_t rmt_alarm_config = {
                                            .reload_count = 0, // counter will reload with 0 on alarm event
                                            .alarm_count = RMT_PLAY_DELAY_MS * 1000, // Set the actual alarm period, since the resolution is 1us, 1000000 represents 1s
                                            .flags.auto_reload_on_alarm = true, // Disable auto-reload function
                                        };

    ESP_ERROR_CHECK(gptimer_set_alarm_action(rmt_gptimer, &rmt_alarm_config));

    gptimer_event_callbacks_t rmt_gptimer_callback = {
                                    .on_alarm = task_setup_struct_ptr->rmt_callback_func_ptr, // Call the user callback function when the alarm event occurs
                                };
    ESP_ERROR_CHECK(gptimer_register_event_callbacks(rmt_gptimer, &rmt_gptimer_callback, task_setup_struct_ptr));
    // Enable the timer

    Audio_GPTimer_Args_Struct timer_cb_args = {
        .tx_chan = i2s_config_ptr->tx_chan,
        .audio_start_queue = start_audio_play_queue,
        .rmt_gptimer_hdnl = rmt_gptimer,
    };

    ESP_ERROR_CHECK(gptimer_register_event_callbacks(audio_gptimer_hndl, &cbs, &timer_cb_args));
    gptimer_enable(rmt_gptimer);

    ESP_ERROR_CHECK(gptimer_enable(audio_gptimer_hndl));
    ESP_ERROR_CHECK(gptimer_start(audio_gptimer_hndl));


    gpio_set_level(XSMT_PIN, 1);

    // while (true)
    // {
        bool use_random = false;
        ESP_ERROR_CHECK(stp_sd__get_new_audio_chunk(audio_chunk_ptr, wave_file_ptr, use_random));

        if(xSemaphoreTake(adc_update_struct_ptr->adc_mutex, portMAX_DELAY) != pdTRUE) ESP_LOGE(TAG, "Error taking adc mutex for volume!");
        double vol_set_perc = (adc_update_struct_ptr->adc_results).vol_percent;
        xSemaphoreGive(adc_update_struct_ptr->adc_mutex);
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
void app_main(void)
{
    char* TAG = "main";

    printf("\33[?25l"); //Hide terminal cursor, quoted from https://stackoverflow.com/questions/30126490/how-to-hide-console-cursor-in-c;

    // gpio_set_direction(CH1_SW_OUTB_PIN, GPIO_MODE_OUTPUT);
    // gpio_set_level(CH1_SW_OUTB_PIN, 1);
    // gpio_set_direction(CH1_SW_OUTA_PIN, GPIO_MODE_OUTPUT);
    // gpio_set_level(CH1_SW_OUTA_PIN, 0);

    stp_sd__spi_config spi_config = {
        .open        = false,
        .mosi_di_pin = PIN_NUM_MOSI,
        .miso_do_pin = PIN_NUM_MISO,
        .clk_pin     = PIN_NUM_CLK,
        .cs_pin      = PIN_NUM_CS,
        .mount_point = "/sdcard",
        .card_ptr    = NULL,
    };

    if(stp_sd__mount_sd_card(&spi_config) != ESP_OK)
    {
        ESP_LOGE(TAG, "Error Mounting SD Card!");
        ESP_LOGI(TAG, "Trying to mount again...");
        vTaskDelay(pdMS_TO_TICKS(1000));
        if(stp_sd__mount_sd_card(&spi_config) != ESP_OK){
            ESP_LOGE(TAG, "Second SD card mount also failed!");
            return;
        }
    }

    BaseType_t flash_light_task_created;
    TaskHandle_t flash_light_task = NULL;
    int flash_light_task_priority = BACKGROUND_TASK_PRIORTIY;
    flash_light_task_created = xTaskCreate(flash_lights, "Flash Lights", 1024, (void*) 0, flash_light_task_priority, &flash_light_task);
    if(flash_light_task_created != pdPASS){
        ESP_LOGE(TAG, "Error creating flashing light task!");
        return;
    }

    SemaphoreHandle_t adc_mutex = NULL;
    adc_mutex = xSemaphoreCreateMutex();
    if( adc_mutex == NULL ) ESP_LOGE(TAG, "Error creating adc semaphore!");

    Adc_Update_Struct adc_update_struct = {0};
    adc_update_struct.adc_mutex = adc_mutex;

    BaseType_t adc_task_created;
    TaskHandle_t update_adc_task = NULL;
    int adc_task_priority = BACKGROUND_TASK_PRIORTIY;
    adc_task_created = xTaskCreate(update_adc, "Update ADC Values", 4096, &adc_update_struct, adc_task_priority, &update_adc_task);
    if(adc_task_created != pdPASS){
        ESP_LOGE(TAG, "Error creating adc update task!");
        return;
    }

    BaseType_t print_task_created;
    TaskHandle_t update_print_task = NULL;
    int print_task_priority = BACKGROUND_TASK_PRIORTIY;
    print_task_created = xTaskCreate(print_to_terminal, "Print to Terminal", 4096, &adc_update_struct, print_task_priority, &update_print_task);
    if(print_task_created != pdPASS){
        ESP_LOGE(TAG, "Error creating print to terminal update task!");
        return;
    }

    stp_sd__wavFile wave_file = {
      .filename = AUDIO_FILENAME,
    };  
    if(stp_sd__open_audio_file(&wave_file) != ESP_OK)
    {
        ESP_LOGE(TAG, "Error Opening Audio File!");
        return;
    }

    QueueHandle_t reload_audio_buff_Queue;
    reload_audio_buff_Queue = xQueueCreate(1, sizeof(stp_sd__reload_memory_data_struct));
    if(reload_audio_buff_Queue == NULL) ESP_LOGE(TAG, "Error creating audio reload queue!");

    stp_sd__reload_memory_Task_struct reload_mem_Task_struct = {
        .reload_audio_buff_Queue = reload_audio_buff_Queue,
        .wave_file_ptr = &wave_file,
    };

    BaseType_t reload_audio_memory_buff_task_created;
    TaskHandle_t reload_audio_memory_buff_task = NULL;
    int reload_audio_memory_buff_task_priority = AUDIO_TASK_PRIORITY;
    reload_audio_memory_buff_task_created = xTaskCreatePinnedToCore(stp_sd__threadsafe_reload_chunk_memory_buffer_Task, "Reload Audio Memory Buffer", 4096, &reload_mem_Task_struct, reload_audio_memory_buff_task_priority, &reload_audio_memory_buff_task, AUDIO_TASK_CORE);
    if(reload_audio_memory_buff_task_created != pdPASS)
    {
        ESP_LOGE(TAG, "Error creating reload audio buffer update task!");
        return;
    }
    
    stp_sd__reload_memory_data_struct reload_memory_struct = {};    //This is the data passed from the play_audio_chunk function to the reload_memory task
                                                                    //It's defined here to be in both tasks scope.
    stp_sd__audio_chunk_setup audio_chunk_setup = {
        .chunk_len_wo_dither        = 9600,    //REQUIRED INPUT: length of chunk in number of samples, not including dither
        .rise_fall_num_samples      = 0,       //REQUIRED INPUT: Number of samples to apply rise/fall scaling to (nominally 96 [1ms @ 96000Hz]) at the beginning and end of the chunk
        .padding_num_samples        = 100,     //REQUIRED INPUT: Number of samples to offset from the beginning and end of the audio data
        .pre_dither_num_samples     = PRE_DITHER_MS/1000*96000,     //REQUIRED INPUT: Number of samples of dither to append to the beginning and end of the audio file (to appease the PCM5102a chip we are using)
        .post_dither_num_samples    = 384,
        .chunk_buf_size_bytes       = NUM_DMA_BUFF*SIZE_DMA_BUFF*sizeof(int32_t)*2, //Factor of four is needed to match i2s buff size.  +1 is added to make the buffer bigger just in case
        .wavFile_ptr                = &wave_file,
        .reload_audio_buff_Queue    = reload_audio_buff_Queue,
        .reload_memory_struct_ptr   = &reload_memory_struct,
        .audio_sample_rate          = SAMPLE_RATE,
    };

    stp_sd__audio_chunk audio_chunk = {};
    stp_sd__init_audio_chunk(&audio_chunk_setup, &audio_chunk);

    stp_audio__i2s_config i2s_config = {
                                        .buf_capacity             = 0,
                                        .buf_len                  = 0,
                                        .num_dma_buf              = NUM_DMA_BUFF,
                                        .size_dma_buf             = SIZE_DMA_BUFF,
                                        .ms_delay_between_writes  = 0,
                                        .bclk_pin                 = I2S_BCK_PIN,    
                                        .ws_pin                   = I2S_WS_PIN,
                                        .dout_pin                 = I2S_DOUT_PIN,
                                        .sample_rate_Hz           = SAMPLE_RATE,
                                        .max_vol_dBFS             = MAX_VOL_DBFS,
                                        .min_vol_dBFS             = MIN_VOL_DBFS,
                                        .set_vol_percent          = 10,
                                        .vol_scale_factor         = 0,
                                        .min_vol_percent          = 2,
                                        .actual_dbFS              = 0,
                                        .preloaded                = false
                                        };
    ESP_ERROR_CHECK(stp_audio__i2s_channel_setup(&i2s_config));

    QueueHandle_t rmt_start_queue;
    rmt_start_queue = xQueueCreate(1, sizeof(int8_t));
    if(rmt_start_queue == NULL) ESP_LOGE(TAG, "Error creating audio play queue!");

    BaseType_t run_rmt_task_created;
    TaskHandle_t run_rmt_task_hndl = NULL;
    int run_rmt_task_priority = RMT_TASK_PRIORITY;
    run_rmt_task_created = xTaskCreatePinnedToCore(run_rmt_Task, "Run RMT Task", 4096, &rmt_start_queue, run_rmt_task_priority, &run_rmt_task_hndl, RMT_TASK_CORE);
    if(run_rmt_task_created != pdPASS)
    {
        ESP_LOGE(TAG, "Error creating run RMT task!");
        return;
    }

    Audio_Task_Setup_Struct play_audio_task_struct = {
        .i2s_config_ptr  = &i2s_config,
        .audio_chunk_ptr = &audio_chunk,
        .wave_file_ptr = &wave_file,
        .adc_update_struct_ptr = &adc_update_struct,
        .rmt_task_to_notify = run_rmt_task_hndl,
        .rmt_start_queue = rmt_start_queue,
        .rmt_callback_func_ptr = start_RMT_output_gptimer_cb,
    };
    
    BaseType_t play_audio_task_created;
    TaskHandle_t play_audio_task_hndl = NULL;
    int play_audio_task_priority = AUDIO_TASK_PRIORITY;
    play_audio_task_created = xTaskCreatePinnedToCore(play_audio_Task, "Play Audio Task", 4096, &play_audio_task_struct, play_audio_task_priority, &play_audio_task_hndl, AUDIO_TASK_CORE);
    if(play_audio_task_created != pdPASS)
    {
        ESP_LOGE(TAG, "Error creating audio play task!");
        return;
    }

    
    
    for(int i=0; i<20; i++)
    { 

        vTaskDelay(pdMS_TO_TICKS(500));
    }

    esp_err_t stp_audio__i2s_channel_disable(stp_audio__i2s_config* i2s_config_ptr);

    if(stp_sd__free_audio_chunk(&audio_chunk) != ESP_OK){
        ESP_LOGE(TAG, "Error destructing audio chunk!");
        return;
    }
    if(stp_sd__close_audio_file(&wave_file) != ESP_OK){
        ESP_LOGE(TAG, "Error closing audio file!");
        return;
    }
    if(stp_sd__unmount_sd_card(&spi_config) != ESP_OK){
        ESP_LOGE(TAG, "Error unmounting SD card");
        return;
    }

        for(int i=0; i<800; i++)
    { 

        vTaskDelay(pdMS_TO_TICKS(500));
    }

    return;
}

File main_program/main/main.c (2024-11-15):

#include <string.h>
#include <math.h>
#include "freertos/FreeRTOS.h"
#include "freertos/task.h"
#include "esp_log.h"
#include "driver/rmt_tx.h"
#include "driver/gptimer.h"
#include <stdint.h>
#include <stdlib.h>
#include <stdint.h>
#include <math.h>
#include "esp_mac.h"
#include "freertos/FreeRTOS.h"
#include "freertos/task.h"
#include "driver/i2s_std.h"
#include "soc/esp32/rtc.h"
#include "esp_timer.h"

#include "driver/gpio.h"
#include "esp_check.h"
#include "sdkconfig.h"
#include <stdio.h>
#include <math.h>
#include <stdlib.h>
#include "esp_system.h" 
#include "esp_task_wdt.h"
#include "esp_sntp.h"



//I2S DEFINITIONS__________________________________________________________________I2S START_______________________I2S START___________________________________


#define _USE_MATH_DEFINES

/* Set 1 to allocate rx & tx channels in duplex mode on a same I2S controller, they will share 
the BCLK and WS signal
 * Set 0 to allocate rx & tx channels in simplex mode, these two channels will be totally separated,
 * Specifically, due to the hardware limitation, the simplex rx & tx channels can't be registered on the same controllers on ESP32 and ESP32-S2,
 * and ESP32-S2 has only one I2S controller, so it can't allocate two simplex channels */
#define EXAMPLE_I2S_DUPLEX_MODE         CONFIG_USE_DUPLEX

#define EXAMPLE_STD_WS_IO1          13      // I2S word select io number
#define EXAMPLE_STD_DOUT_IO1        12     // I2S data out io number
#define EXAMPLE_STD_BCLK_IO1        11      // I2S bit clock io number

#define BITS_IN_32BIT               2147483647
#define VOL_PERCENT                 10

#define SAMPLE_RATE                 96000
#define DURATION_MS                 50
#define WAVEFORM_LEN                SAMPLE_RATE/1000*DURATION_MS
#define NUM_DMA_BUFF                6
#define SIZE_DMA_BUFF               800
#define I2S_BUFF_SIZE               NUM_DMA_BUFF * SIZE_DMA_BUFF

static i2s_chan_handle_t                tx_chan;        // I2S tx channel handler

int i;

// const int SAMPLE_RATE = 16000;
// const int DURATION_MS = 10;
int FREQUENCY          = 1000;


void create_sine_wave(int32_t * waveform, double * waveform_double, int FREQUENCY) {
    // Calculate the number of samples
    printf("Free heap size before allocation: %lu bytes\n", esp_get_free_heap_size());

    printf("Num Samples: %d\n", WAVEFORM_LEN);
    printf("Size of double: %u\n", sizeof(double));

    // Allocate memory for the waveform array
    // int32_t *waveform = (int32_t *)malloc(WAVEFORM_LEN * sizeof(int32_t));
    printf("Free heap size after allocation: %lu bytes\n", esp_get_free_heap_size());

    // Check if memory allocation was successful
    if (waveform == NULL) {
        printf("Memory allocation failed!\n");
        // return NULL;  // Return NULL if allocation failed
    }

    // Populate the waveform array with sine values
    for (int i = 0; i < WAVEFORM_LEN; i++) {
        double timestep = (double)i / (double)SAMPLE_RATE;
        double volume = (double)VOL_PERCENT / (double)100;                  //Operands must be cast to double for this to work.
        // printf("Volume: %0.10f\n", volume);
        double sine_point = (volume * sin(2 * M_PI * FREQUENCY * timestep));  // Use 2 * PI for full sine wave cycle
        int32_t int_point = (int32_t)(sine_point*BITS_IN_32BIT);
        (waveform_double[i]) = sine_point;
        (waveform[i]) = int_point;
    }
    printf("Made it through sine wave function\n");

}


static void i2s_write_function(void *waveform)
{    
    // printf("\n5\n");

    int32_t *audio_waveform = (int32_t*)waveform;           //Cast the waveform argumen to a 32-bit int pointer
    // printf("\n6\n");

    size_t WAVEFORM_SIZE = (int32_t)WAVEFORM_LEN * sizeof(int32_t);
    // printf("Here");

    int32_t *w_buf = (int32_t *)calloc(sizeof(int32_t), WAVEFORM_LEN);   //Allocate memory for the I2S write buffer
    assert(w_buf);                                          //Check if buffer was allocated successfully
    size_t w_bytes = I2S_BUFF_SIZE;                         //Create variable to track how many bytes are written to the I2S DMA buffer
    size_t audio_samples_pos = 0;                           // Keep track of where we are in the audio data


    /*Here we iterate through each index in the audio waveform, and assign the value to the wbuf*/
    while (audio_samples_pos<WAVEFORM_LEN) {
        w_buf[audio_samples_pos] = (audio_waveform[audio_samples_pos]);
        audio_samples_pos++;
        }


    /*Here, we initialize our time-tracking and index-tracking variables*/
    float start_time_us = (float)esp_timer_get_time();
    // printf("Time Of Loop Start: %0.6f ms", start_time_us/(float)1000);
    float curr_time_us = start_time_us;
    float last_time_us = curr_time_us;
    float period_us    = 0;
    int idx = 0;

    /*This begins the sound-writing loop, which is limited to 300 iterations for testing purposes*/
    // while(idx < 300){           

    /*The I2S channel is enabled and disabled every loop.  This has been found to enable the most repeatable results*/
    // ESP_ERROR_CHECK(i2s_channel_enable(tx_chan));       

    /*Find current time and period of last loop*/
    curr_time_us = (float)(esp_timer_get_time()) - start_time_us;   
    period_us = curr_time_us - last_time_us;
    last_time_us = curr_time_us;

    /*Iterate through and write wbuf to I2S DMA buffer.  If len(wbuf) were > than I2S buff size, 
    we would use the wbytes variable to move along wbuf and start a new write at the position where the 
    last one left off.  That's not the case here, though*/
    for (int tot_bytes = 0; tot_bytes < WAVEFORM_SIZE; tot_bytes += w_bytes){

        i2s_channel_write(tx_chan, w_buf, WAVEFORM_SIZE, &w_bytes, DURATION_MS);

    };

    // printf("Current Loop Time: %0.1f ms\n", curr_time_us/1000);
    // printf("Current Loop Period: %0.6f ms\n", period_us/1000);

    // ESP_ERROR_CHECK(i2s_channel_disable(tx_chan));      //Disable channel each loop, as described above
    
    idx++;


    free(w_buf);
    printf("Loop Ended\n");
}
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

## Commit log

2023-11-05 Initial release
    [PCB_one_rev4-B_Adhesive.gbr, PCB_one_rev4-B_Cu.gbr, PCB_one_rev4-B_Mask.gbr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]
2024-03-29 Re-organized folder
    [CPL-Rev 6.csv, Rev 6-CuTop.gbr, Rev 6-EdgeCuts.gbr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]
2024-03-29 Added fixture CAD model
    [bimodal_device_fixture v12.step]
2024-10-22 Intial move of project to github
    [bimodal_device_fixture v12.step]
2024-10-27 Fixed callocs and otehr housekeeping. Tested increasing waveform duration but stack size isn't big enough. This one works
    [main.c]
2024-10-27 Got I2S working on ESP32 - S3
2024-11-02 Updated RMT Test with trimming to improve suynchronization of channels. Confirmed that synchronization works with the ESP32-S3
2024-11-02 Confirmed Effectiveness of using I2S with RMT. Currently, closest delay is 12.5ms
2024-11-02 Increased sample rate to 44100. Delay between sound and pulse increased to 20ms. Seems to be issue with i2s
    [main.c]
2024-11-02 Updated, code is working except for the delay timing. Connection issues cause false alarms w.r.t. i2s working
    [main.c]
2024-11-09 Corrected 20 ms delay after I2S write. Sum of I2S buffer must be equal to the length of the payload. auto-clear true. don't enable/disable with every write
    [backup.c, main.c]
2025-07-06 Reorganized folder structure and added folder for SD card operations
    [bimodal_device_fixture v12.step]
2025-07-07 Implemented a rough wave file parser and confirmed its functionality on the device. Started on the rng implementation of selecting chunks of the audio file.
2025-07-11 Debugged and fixed audio chunk getter function
    [stpsd_sd_sdcardoperations.c]
2025-07-15 Completed first pass of i2s write and preload functions
    [White Noise Audio File Data.xlsx]
2025-07-19 I2S writing with preload is mostly working. More work is needed to overcome issues with soft mute of PCM5102a chip.
    Former-commit-id: 3380aa73cd6dc00d4ae94a5da3eee82436e23942
    [main.c, stp_sd_sdcardops.c]
2025-07-31 Got I2S output working, using 30ms of dither to overcome power-up artefacts
    Former-commit-id: 7cbd1f22fb0ea0932767ffc88d02489cd193fc80
2025-07-31 Reset project - poor behavior with audio turn-on has returned. Unclear what the cause is
    [bimodal_device_fixture v12.step]
2025-08-06 Implemented a separate file to handle adc operations - got the adc for the volume control and ch1 knob working.
2025-10-05 Changed adc read sync from queue to mutex. Fixed alignment of fread buffer updates. Still having issues getting full audio to play
    [White Noise Audio File Data.xlsx]
2025-10-11 Multi-threaded loading of audio files confirmed to be working. Playing audio chunk of 1 second in length successfully. Confirmed that data being sent is correct
    [main.c, stp_sd_sdcardops.c]
2025-11-14 Added PWM and started to get it working. Revert to here if needed.
    [main.c, stp_adc.c]
2026-02-20 Changed CMake file to add more gcc error checking flags
    [main.c, stp_sd_sdcardops.c]
2026-08-02 Added custom RMT driver to git repo for version control
2026-08-02 Added updated audio i2s driver to repo
